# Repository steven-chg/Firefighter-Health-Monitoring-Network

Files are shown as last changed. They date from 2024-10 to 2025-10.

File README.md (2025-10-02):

# Firefighter Health Monitoring Network

A wearable health monitoring system that enables real-time tracking of firefighters' vital signs and environmental conditions during active duty. The system utilizes a mesh network of ESP32-based devices to continuously monitor and transmit critical health data including:

- Heart rate
- Motion 
- GPS location tracking
- Surrounding temperature measurements

## Key Features
- Wearable sensors integrated into firefighter gear
- Central monitoring hub for incident commanders with intuitive GUI 
- Real-time alerts for abnormal vital signs
- Mesh network with 300m+ urban range
- 2+ hour battery life in high temperature conditions

## Demo
Watch the demo video (https://youtu.be/pz7b-LwFBLg)

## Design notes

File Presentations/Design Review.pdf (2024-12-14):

ECE 445 Senior Design | Group 17: Firefighter Health Monitoring Network

# Group 17: Firefighter Health Monitoring Network

Members:
Bryan Chang (chchang9)
Kevin Huang (kuanwei2)
Steven YM Chang (sychang5)

# Contents

## I. Problem Statement and Solution II. Visual Aid III. High-Level Requirements IV. Block Diagram and Schematic V. Requirements and Verification Tables VI. Tolerance Analysis VII. Cost Analysis VIII. Schedule and Division of Labor IX. Ethics and Safety

# 1. Problem Statement and Solution

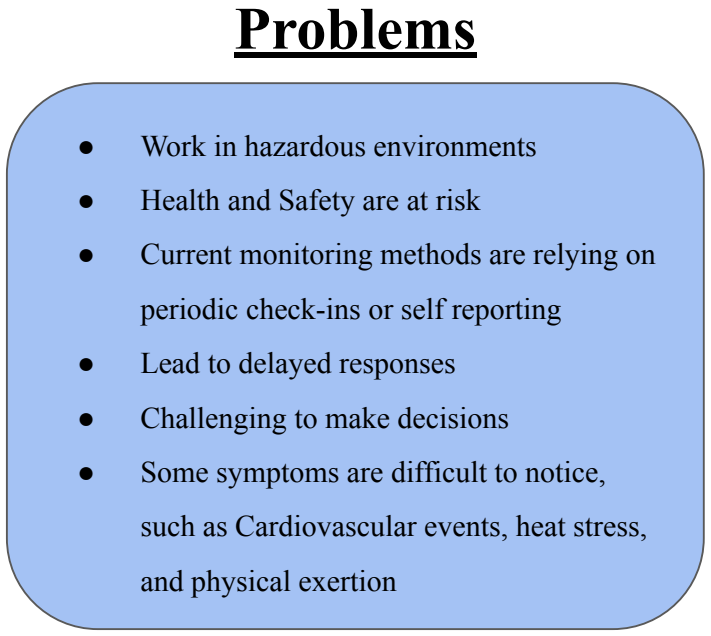
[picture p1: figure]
● Work in hazardous environments; ● Health and Safety are at risk; periodic check-ins or self reporting; ● Lead to delayed responses; ● Challenging to make decisions; and physical exertion; Problems

- Current monitoring methods are relying on
- Some symptoms are difficult to notice,

such as Cardiovascular events, heat stress,

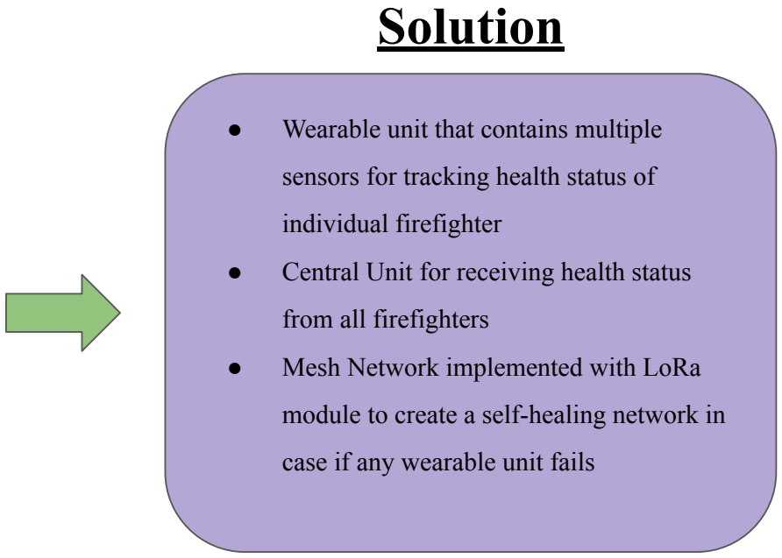
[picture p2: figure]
● Wearable unit that contains multiple; sensors for tracking health status of; individual firefighter; from all firefighters; ● Mesh Network implemented with LoRa; case if any wearable unit fails; Solution

- Central Unit for receiving health status

module to create a self-healing network in

# 2. Visual Aid

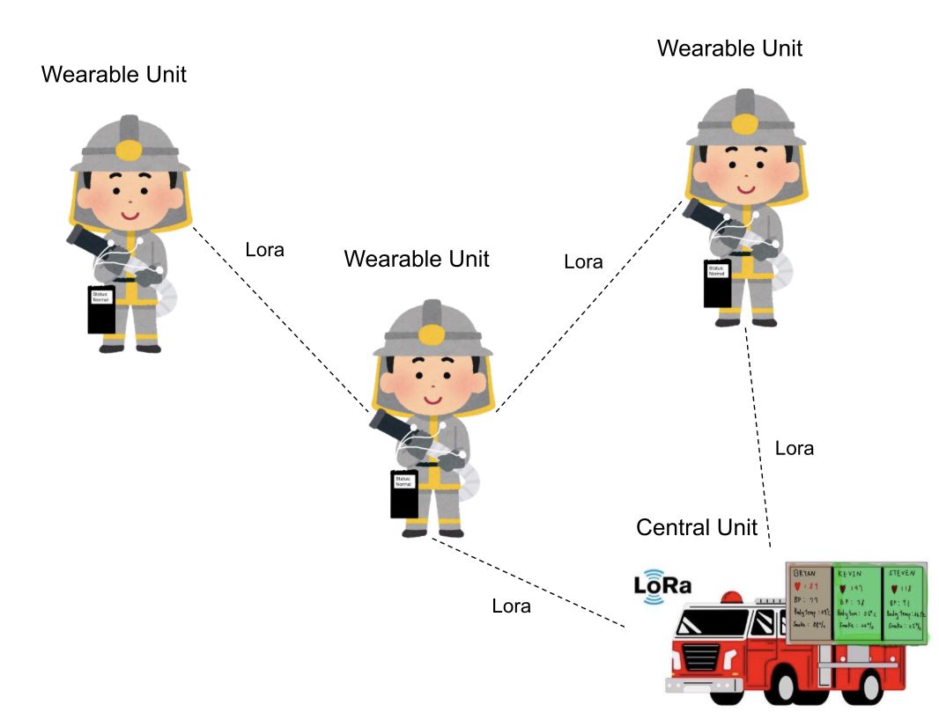
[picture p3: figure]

# 2. Visual Aid

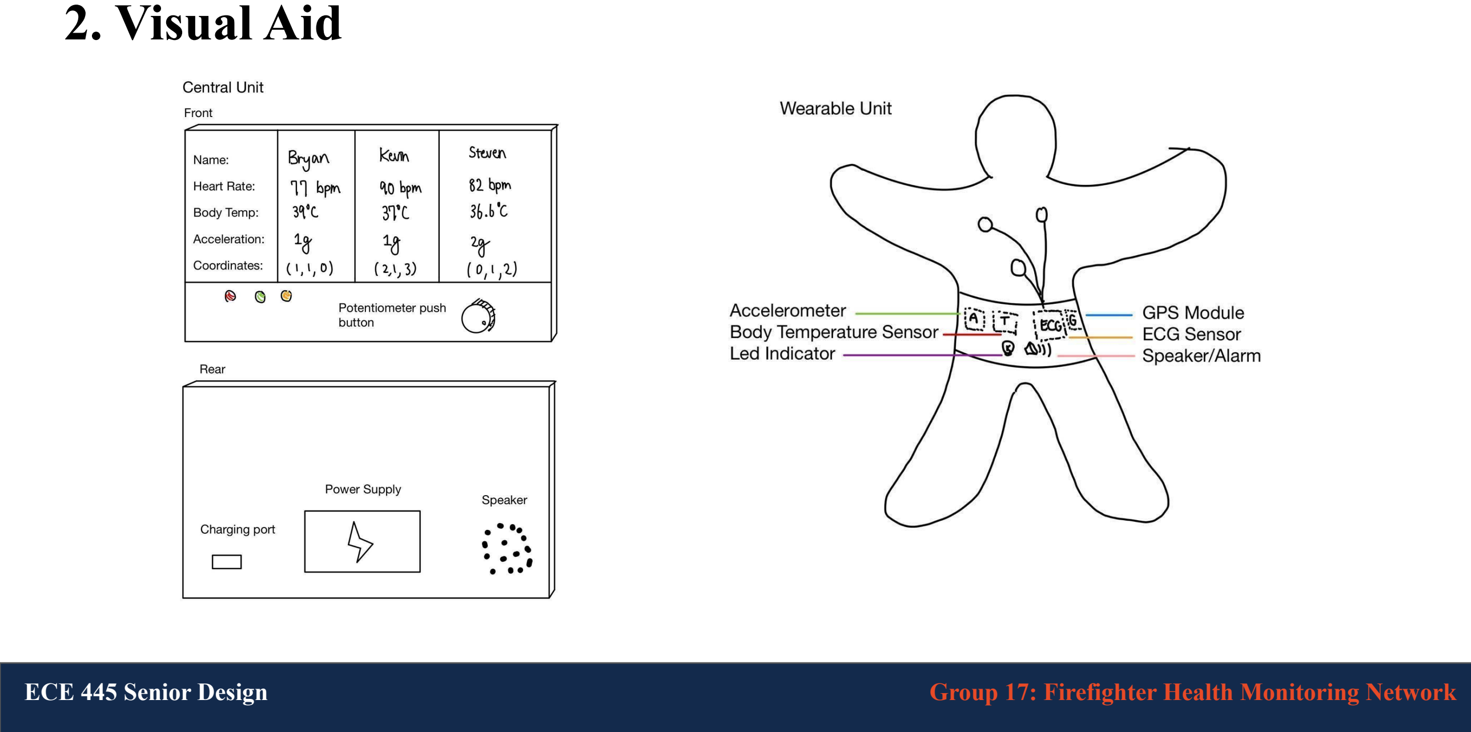
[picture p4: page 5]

# 3. High-Level Requirements

## 1. The system shall continuously monitor and transmit the following data with 90%

## accuracy and operate on a single charge for at least 2 hours in typical fire fighting

conditions above 30°C.

a. ECG/EKG Data
b. GPS Location
c. Motion Data
d. Surrounding Temperature Data

# 3. High-Level Requirements

## 2. The system shall generate buzzer alerts on the wearable unit and central monitor

## within 10 seconds of abnormal detections based on thresholds on data from sensors:

a. ECG/EKG Data
i. Heart rates <40 bpm or >150 bpm sustained for >30 seconds, or upon detection of specified

arrhythmias.

b. Motion Data
i. No significant motion detected for >60 seconds
c. Surrounding Temperature Data
i. Temperature exceeds 40°C for more than 3 minutes

# 3. High-Level Requirements

## 3. The mesh network shall maintain connectivity in challenging environments with a

## minimum range of 300 meters in urban settings and 1 km in open areas, using LoRa

## technology. The system shall automatically route data through multiple hops

## (firefighter-to-firefighter) to reach the central unit when direct communication is not

possible. End-to-end data transmission time from any firefighter to the central unit shall

not exceed 15 seconds, even when relaying through multiple nodes.

# 4. Block Diagram

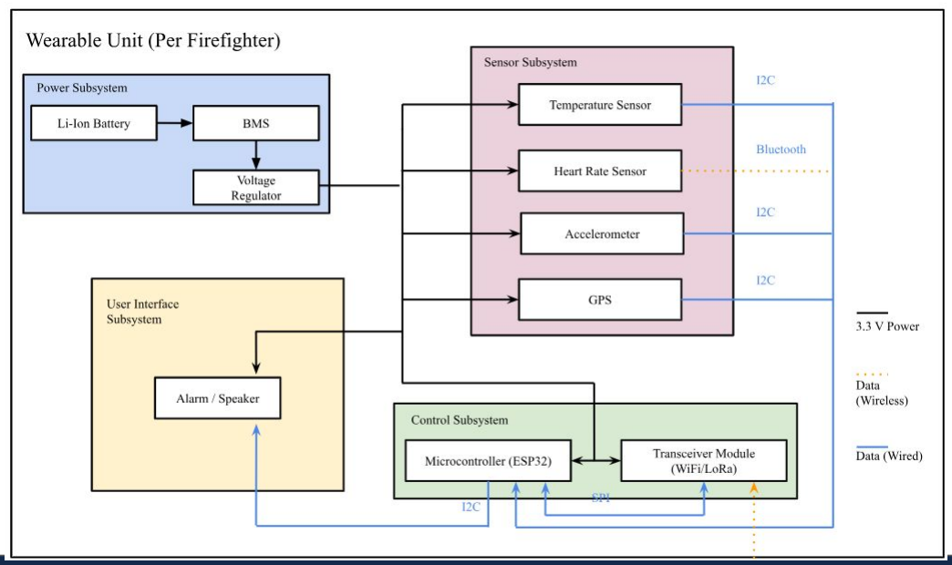
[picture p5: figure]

# 4. Block Diagram

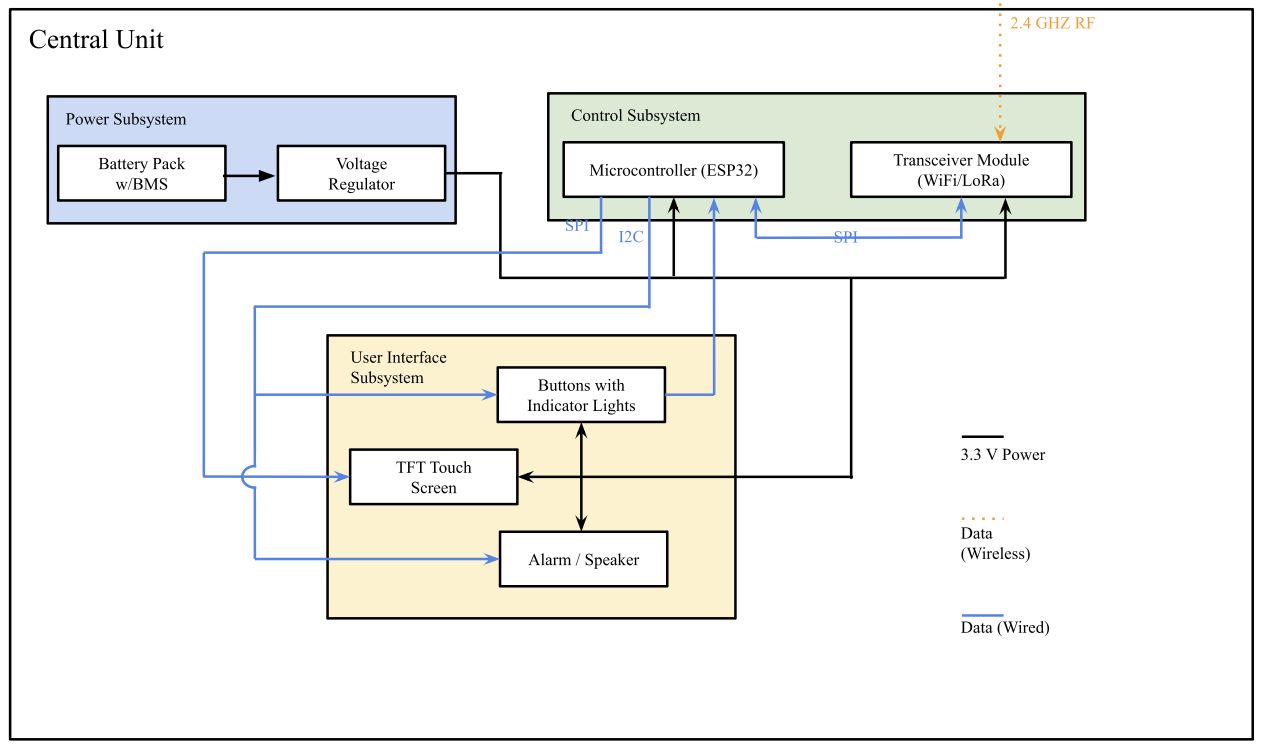
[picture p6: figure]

# 4. Wearable Unit Schematic

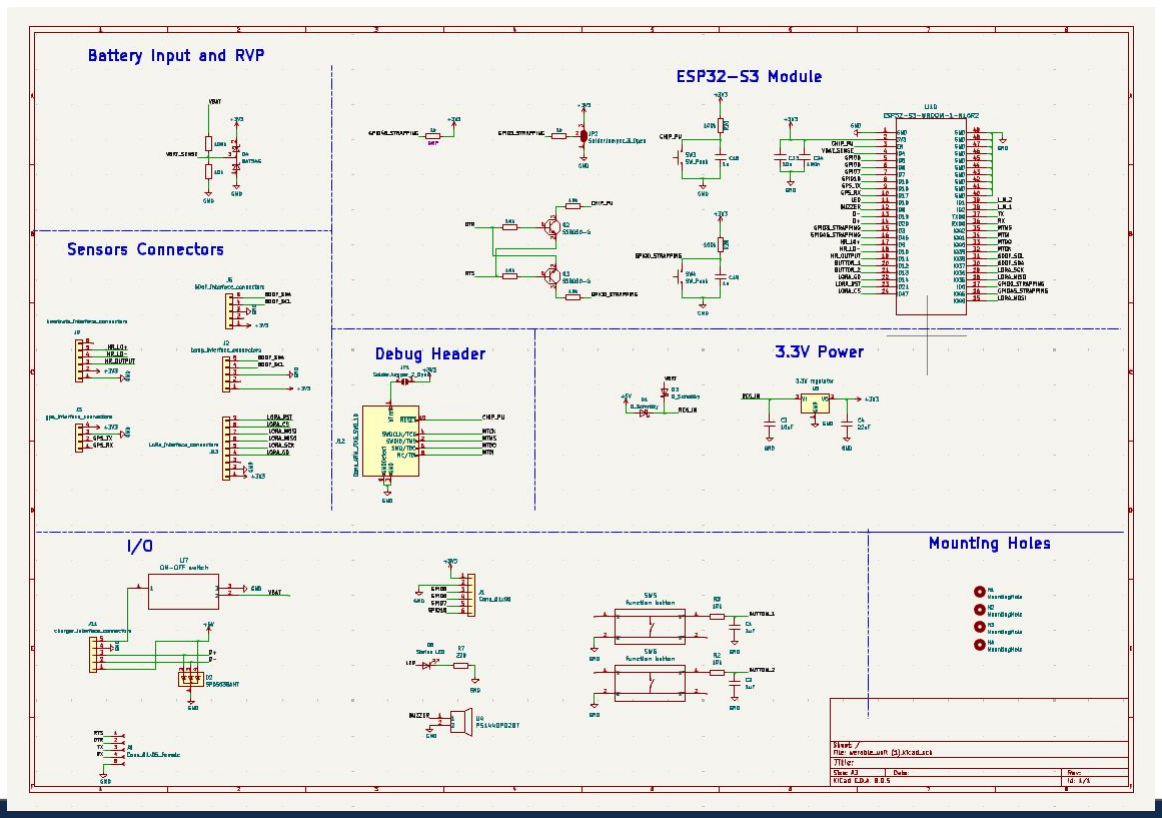
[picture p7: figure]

# 4. Wearable Unit

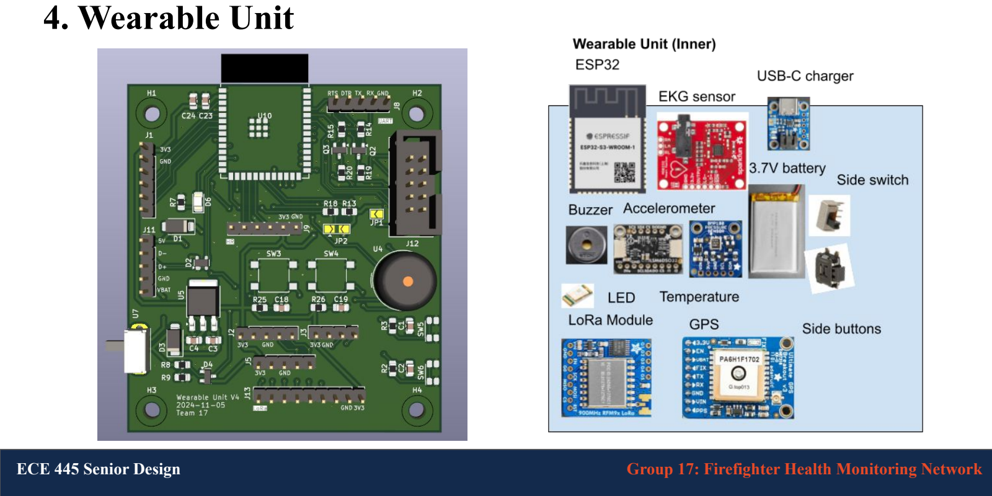
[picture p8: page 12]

# 5. Requirements and Verification

## Wearable Sensor Subsystem

This subsystem is responsible for continuously collecting real-time health and environmental data from individual firefighters. The sensors track vital signs like heart rate, surrounding temperature, and motion. The data is sent to the mesh network of the ESP32 and the central hub via reliable communication methods ESP-MESH and LoRa. The enclosure will be designed using 3D Computer-aided design software and printed out using a 3D printer with Polylactic acid material (PLA). Although PLA might have lower heat-resistance, other material like Polyetheretherketone (PEEK) could be replaced with the same design but with higher cost. For the purpose of this project, we will prioritize the design.

## 5. Requirements and Verification: Wearable Sensor Subsystem

Requirements | Verification

Wearable unit measures the surrounding temperature, heart rate, acceleration, and location of the user and sends it to the Central Monitoring Hub subsystem with a 90% accuracy.

1. Place a thermometer in a closed box and see if the values are the same for the device and the thermometer
2. Place the device on a person equipped with Apple Watch and validate the heartbeat count
3. Place the device on a steady surface and see if the acceleration read is equal to gravity (9.8m/s²
)
4. Measure the current coordinate with phone and validate the values from the gps sensor in the wearable unit
5. Output the readings to a terminal and confirm that the central unit is reading the values in real time

Alert is generated if a firefighter’s heart rate exceeds 150 bpm or falls below 40 bpm for more than 30 seconds. These thresholds account for both sustained tachycardia and bradycardia, indicating potential danger to the firefighter’s health.

1. Simulate the heart rate readings using ADALM2000
2. Set the wearable unit to monitor heart rates while gradually increasing to 160 bpm and decreasing to 35 bpm.
3. Validate that the wearable unit triggers an alert when heart rate exceeds 150 bpm for more than 30 seconds and when it falls below 40 bpm for the same duration.
4. Record response times and ensure alerts are activated correctly.

## 5. Requirements and Verification: Wearable Sensor Subsystem

Requirements | Verification

Alert is generated when the temperature exceeds 40°C for more than 3 minutes.

1. Place the device nearby a stove (or controlled heat source) to gradually increase the temperature around the wearable unit.
2. Monitor the wearable unit’s temperature sensor and record readings.
3. Validate that the wearable unit triggers an alert when the temperature exceeds 40°C for more than 3 continuous minutes.

Alert is generated if no significant movement is detected on the firefighter for over 60 seconds.

1. Secure the wearable unit to a stationary object or user.
2. Ensure that no movement is detected (within a calibrated margin) for a continuous period of 60 seconds, and verify that an alert is triggered at that moment.
3. Test with varying degrees of movement to ensure the threshold for "significant movement" is correctly calibrated.

## 5. Requirements and Verification: Wearable Sensor Subsystem

Requirements | Verification

In emergency situations where one or more alerts have been triggered, the GPS update frequency increases from every 30 seconds to every 5 seconds.

1. Trigger one of the alerts (heart rate, temperature, or motion) while monitoring the GPS update frequency.
2. Have the person wearing the monitoring unit be continuously moving.
3. Record the GPS update intervals to verify that the unit updates every 5 seconds during an alert condition.
Reset the device if the button is pressed | 1. | Press the button and verify the device restarts

# 5. Requirements and Verification

## Central Monitoring Hub Subsystem

The central hub acts as the control center for the network, gathering and visualizing health data from all firefighters in real time. It allows incident commanders to monitor the team’s health status, detect potential health risks, and respond quickly to emergencies. Its rugged design ensures that it remains operational during operations in harsh environments. The enclosure will be designed using 3D Computer-aided design software and printed out using a 3D printer with Polylactic acid material (PLA). Although PLA might have lower heat-resistance, other materials like Polyetheretherketone (PEEK) could be replaced with the same design but with higher cost. For the purpose of this project, we will prioritize the design.

## 5. Requirements and Verification: Central Monitoring Hub Subsystem

Requirements | Verification

The central unit display should be able to visualize the firefighter data holistically

Have three wearable device sending out simulated information to the central unit to verify it is able to display the firefighters data holistically

Send out a critical alert and change of LED color when abnormal activities occur

Manually input data with different conditions (normal, abnormal, dangerous) to the subsystem and observe whether the alert is turned on or off and whether the LED color changes according to the condition

# 5. Requirements and Verification

Power Subsystem

The power subsystem ensures that both the wearable units and the central hub have the energy to operate continuously.

Power Consumption for Wearable Unit:
ESP32 Microcontroller (DOIT ESP32 DEVKIT V1): 2.2V to 3.6V at ~100mA to 200mA (Active)
Electrocardiogram Sensor (ECG/EKG Sensor) (SEN-12650): 3.3V to 5V at ~10 mA
Temperature Sensor (BMP 180): 3.3V at ~5 µA (1 sample/second in standard mode)
Accelerometer for Motion Detection (LSM6DS032): 1.71V to 3.6V at ~1.5 mA (Active Operation) and ~0.5 µA (Low-Power Mode) GPS Module (MAX-M10S): 3.3V VCC at ~6mA to ~25mA
Buzzer (PS1240): 1.71V to 3.6V at ~20mA
LoRa Module for Extended Communication (RFM95W): 1.8V to 3.7V at 13.5 mA (Transmission) and 10 mA (Reception)

Power Consumption for Central Monitoring Unit:
ESP32 Microcontroller (DOIT ESP32 DEVKIT V1): 2.2V to 3.6V at ~100mA to 200mA (Active)
LoRa Module for Extended Communication (RFM95W): 1.8V to 3.7V at 13.5 mA (Transmission) and 10 mA (Reception) 3.5" TFT Touch Screen (HX8357D): 3.3V at ~20 mA to ~40 mA
Buzzer (PS1240): 1.71V to 3.6V at ~20mA

## 5. Requirements and Verification: Power Subsystem

Requirements | Verification

Wearable units should send alerts when the battery is low (below 10%) to the central unit.

Charge the device to 15% and operate the device until the battery drops down to 10% measuring with a multimeter to verify if the alert is sent.

Both the wearable unit and the central unit should last at least 2 hours on a single charge under typical operation conditions (temperatures above 30°C).

Simulate the sensor readings using ADALM2000, record the battery voltage every 5 mins to verify both the wearable unit and central unit has battery life longer than 2 hours.

# 5. Requirements and Verification

## User Interface Subsystem

The user interface is designed to provide incident commanders with a comprehensive and intuitive platform for monitoring firefighter health data in real time. It features a custom-designed graphical user interface on a 3.5" TFT touch screen, ensuring clear visibility and easy navigation.

## 5. Requirements and Verification: User Interface Subsystem

Requirements | Verification

Custom-designed graphical user interface (GUI) for the 3.5" TFT touch screen

1. Visually inspect GUI layout on the actual 3.5" screen
2. Perform touch interaction tests covering all UI elements
3. Verify responsiveness and accuracy of touch inputs

Real-time data visualization components (graphs, charts, status indicators)

1. Simulate data input for graphs, charts, and status indicators
2. Verify real-time updates of visualizations
3. Test different data scenarios (normal, critical, edge cases)
4. Measure and verify update frequency matches requirements

## 5. Requirements and Verification: User Interface Subsystem

Requirements | Verification

Alert management system with visual and auditory cues

1. Trigger various alert conditions
2. Verify visual cues appear correctly on screen
3. Test auditory alerts for proper sound and volume
4. Confirm alert prioritization works as designed
5. Test alert acknowledgment and dismissal functionality

User input handling for system configuration and data queries

1. Test all system configuration options
2. Verify data query functionality with various input parameters
3. Confirm changes are applied and persist after system restart
4. Test edge cases and invalid inputs for proper error handling

# 5. Requirements and Verification

## Mesh Network Integration

The LoRa Mesh Network provides long-range communication between nodes, ensuring connectivity even when traditional communication infrastructure is unavailable. This system enables reliable data transmission from firefighters' wearable units to the central hub in challenging environments.

## 5. Requirements and Verification: Mesh Network Integration

Requirements | Verification

End-to-end (including hops) data transmission time from any firefighter to the central unit shall not exceed 15 seconds, even when relaying through multiple nodes. Communication range of at least 1 km in open areas and 300 meters in urban environments.

Calculate the differences between the wearable unit packet sent time using gps time vs the central unit received time to verify the communication time is within 15 seconds.

The devices should be able to create its mesh network so even if a wearable is not directly in range to the central unit it can hop between the other wearable that’s in range to connect to the central unit

1. Set up a test environment with multiple wearable units and obstacles to force multi-hop routing.
2. Gradually move units out of direct range of the central hub.
3. Verify data from out-of-range units successfully reaches the central hub via other units.
4. Use network visualization tools to confirm the mesh topology.
5. Simulate node failures to test self-healing capabilities.
6. Measure and compare latency for direct vs multi-hop communications.

## 5. Requirements and Verification: Health Status Assessment Data Processing

Requirements | Verification

For ECG signals, use filtering techniques, such as a low-pass filter with a cut-off frequency of 100 Hz to remove high-frequency noise, combined with a stop-band filter around 60 Hz to eliminate electrical noise interference

1. Use Matlab to plot raw and filtered ECG signals in the time domain.
2. Compare frequency spectra of raw and filtered signals using FFT.
3. Verify attenuation above 100 Hz and at 60 Hz.

For ECG signals, apply the Butterworth or Chebyshev filter to ensure sufficient attenuation of at least -60 dB/decade in the stopband, preserving the integrity of the ECG signal’s primary components (P, QRS, T waves).

1. Apply the chosen filter (Butterworth or Chebyshev) to a known ECG signal.
2. Plot the frequency response of the filter and measure the attenuation in the stopband to confirm it meets or exceeds -60 dB/decade.
3. Compare the filtered signal with the original in both time and frequency domains to ensure preservation of P, QRS, and T waves.
4. Perform a quantitative analysis (e.g., cross-correlation) between original and filtered signals to verify integrity of primary components.

# 6. Tolerance Analysis

## LoRa Communication Range

Requirement:

The LoRa module must ensure a communication range of at least 1 km in open areas and 300 meters in urban or obstructed environments.

Analysis:

To assess the feasibility of meeting this requirement, we'll consider the following factors:

1. LoRa Link Budget
2. Environmental Factors
3. Transmission Power

# 6. Tolerance Analysis

## 1. LoRa Link Budget

Link Budget = Transmitter Power + Transmitter Antenna Gain - Path Loss + Receiver Antenna Gain - Receiver Sensitivity

Assuming typical values for a LoRa system:

- Transmitter Power: 14 dBm (25 mW)
- Transmitter Antenna Gain: 2 dBi
- Receiver Antenna Gain: 2 dBi
- Receiver Sensitivity: -137 dBm (for SF12, BW125)

# 6. Tolerance Analysis

The path loss for 1 km in an open area can be estimated using the free-space path loss formula:

FSPL (dB) = 20 * log10(d) + 20 * log10(f) - 147.55

Where:

- d = distance in meters (1000)
- f = frequency in Hz (assume 915 MHz for US LoRa)

FSPL = 20 * log10(1000) + 20 * log10(915*10^6) - 147.55 ≈ 92 dB

Link Budget = 14 + 2 - 92 + 2 + 137 = 63 dB

This positive link budget suggests that communication at 1 km in open areas is feasible.

## 1. LoRa Link Budget

# 6. Tolerance Analysis

In urban or obstructed environments, additional path loss occurs due to obstacles. We can estimate this additional loss to be around 20-30 dB.

For 300 meters in an urban environment:

- FSPL = 20 * log10(300) + 20 * log10(915*10^6) - 147.55 ≈ 81 dB
- Total Path Loss = 81 dB + 25 dB (urban environment) = 106 dB
- Link Budget = 14 + 2 - 106 + 2 + 137 = 49 dB

This positive link budget indicates that communication at 300 meters in urban environments is also feasible.

## 2. Environmental Factors

# 6. Tolerance Analysis

The analysis uses 14 dBm (25 mW) as the transmission power. Many LoRa modules can transmit at up to 20 dBm (100 mW), which would

add an extra 6 dB to the link budget if needed.

## 3. Transmission Power

# 6. Tolerance Analysis

## Resilience of Mesh Network Communication to Maximum Allowable Delay

Requirement:

- Node Connectivity: Each wearable device must communicate with neighboring devices to relay data back to the central hub.
- Maximum Latency: The total transmission delay from a firefighter's device to the central unit must not exceed 15 seconds.

Analysis:

We'll consider the following factors:

1. Transmission Time Using LoRa
2. Maximum Number of Hops

# 6. Tolerance Analysis

LoRa communication allows for long-range transmission with low data rates. LoRa uses a feature called the spreading factor (SF) to control

the trade-off between data rate and range. As the distance between the transmitter and receiver increases, you may need to increase the

spreading factor to maintain reliable communication.

Assuming a payload size of 400 bytes (3200 bits) and using a data rate of 3.13 kbps ( for 3km in Open Areas and 500m in Urban

Environments):

Transmission Time = 3200 bits / 3130 bps = 1.02 seconds (1022 ms)

This calculation indicates that transmitting data between neighboring firefighters will take approximately 1022 ms per hop.

## 1. Transmission Time Using LoRa

# 6. Tolerance Analysis

Given a maximum allowable total delay of 15 seconds, we can calculate the maximum number of hops n:

n=15000 ms / 1022 ms ≈ 14.68 hops

While this theoretical maximum is high, practical application in a firefighting context is much lower. Considering a typical firefighting team

size of 4 to 10 members, our analysis demonstrates that the mesh network can reliably support up to 14 hops between firefighters while still

adhering to the 15-second maximum allowable delay for data transmission. This is based on a payload size of 400 bytes and a data rate of

3.13 kbps using LoRa communication.

## 2. Maximum Number of Hops

# 6. Tolerance Analysis

## Power Management

Requirement:

- The battery should last at least 2 hours on a single charge under typical operation conditions (temperatures above 30°C). Analysis:
1. Battery Capacity (C): 2000 mAh lithium-ion battery.
2. Power Consumption (P): Total power consumption depends on the combined power draw of the sensors, ESP32 microcontroller, and communication modules (LoRa, ESP-MESH). The following current draw is based on the upper bound of current consumption data included in the power subsystem section.
3. Battery Discharge Efficiency (n): Efficiency factor, assume 60% due to heat and inefficiencies in power delivery (conversion losses).

# 6. Tolerance Analysis

- Power Consumption of each Components
- ESP32 microcontroller: 200 mA during active use.
- EKG sensor: 10 mA.
- Temperature sensor: 5 µA.
- GPS sensor: 25 mA
- Motion sensors (accelerometer/gyroscope): 1.5 mA.
- LoRa module: 13.5 mA during transmission.
- Buzzer: 20 mA
- P = 200 mA + 10 mA+ 5 µA +25 mA+ 1.5 mA + 13.5 mA + 20 mA<=271mA

## 1. Total Power Consumption

# 6. Tolerance Analysis

To calculate the battery runtime, we can use the following formula: t = C*nP

Where:
- t is the battery runtime in hour
- C is the battery capacity in mAh
- n is the battery discharge efficiency
- P is the total power consumption

P = 200 mA + 10 mA+ 5 µA +25 mA+ 1.5 mA + 13.5 mA + 20 mA<=271mA

As a result, we get t = C*n / P=2000*0.6 / 271 = 4.43hr >= 4hr

Thus, the battery is expected to last approximately 4 hours under typical usage conditions, which satisfies the requirement of 2 hours of operation.

## 2. Battery Runtime Calculation

# 7. Cost Analysis

## Three Subcategories

## 1. Purchased Components and Parts

## 2. Labor and Wages

## 3. Other Resources

## 1. Purchased Components and Parts

Description | Manufacturer | Part Number | Quantity | Unit Price | Extended Price | Part Link
GPS | SparkFun | MAX-M10S | 1 | $44.95 | $44.95 | Link (https://www.sparkfun.com/products/18037)
LoRa Transceiver | Adafruit | RFM95W | 3 | $19.95 | $59.85 | Link (https://www.adafruit.com/product/3072?gad_source=1)

3.5" TFT LCD

Single Lead Heart

Display | Adafruit | HX8357D | 1 | $39.95 | $39.95 | Link (https://www.adafruit.com/product/2050)
Rate Sensor | Sparkfun | SEN-12650 | 1 | $21.50 | $21.50 | Link (https://www.digikey.com/en/products/detail/sparkfun-electronics/SEN-12650/5824153?gad_source=1)
Temperature Sensor | Adafruit | BMP 180 | 1 | $9.95 | $9.95 | Link (https://www.adafruit.com/product/1603)

Accelerometer and
Gyroscope | Adafruit | LSM6DS032 | 1 | $12.50 | $12.50 | Link (https://www.adafruit.com/product/4692?gad_source=1)
Piezo Buzzer | PDK Corporation | PS1240 | 2 | $1.50 | $3.00 | Link (https://www.adafruit.com/product/160)
Lithium Ion Battery | Adafruit | 3.7V 2000mAh | 3 | $12.50 | $37.50 | Link (https://www.adafruit.com/product/2011)
Micro-Lipo Charger | Adafruit | Micro-Lipo Charger | 3 | $4.90 | $14.70 | Link (https://www.adafruit.com/product/4410)
ESP32-WROOM | Espressif Systems | DOIT ESP32 DEVKIT V1 | 3 | $15.98 | $47.94 | Link (https://www.amazon.com/ESP32-WROOM-32-Development-ESP-32S-Bluetooth-Arduino/dp/B084KWNMM4)

Total Purchased Components Price: $291.84

## 2. Labor and Wages

- Annual salary for Computer Engineering students as a reference ($109,176/yr according to the Grainger College of Engineering)
- The number of work days in a year is approximately 365*(5/7) ≈ 261 days.
- Assume a person works 8 hours a day and 261 days per year
- Wage per hour is roughly $109,176 / (261*8hr) ≈ $52/hr.
- Over the course of 2 months, we plan to spend an average of 2 hours per day. Thus, the total labor cost will be $52/hr * 2 hr/day * 60

days * 3 students = $18720.

## 3. Other Resources

- Design doesn’t require any customized enclosure for the product, we do not plan to order any part from the ECE Machine shop.
- Plan to use the Senior Design Lab resources, such as PCB creation, multimeters for debugging, and soldering, which has no cost.

# 7. Cost Analysis

## Total Cost

## 1. Purchased Components and Parts: $291.84

## 2. Labor and Wages: $18,720

## 3. Other Resources: $0

## Total Cost: $19,011.84

# 8. Schedule and Division of Labor

Role | Name | Specialized Work
Network Communications Specialist | Kevin Huang | ● Mainly focus on Mesh Network and Data Transfer ● In charge of implementing and optimizing the mesh network ● Will ensure reliable data transmission in challenging environments
Lead Hardware Engineer | Bryan Chang | ● Mainly focus on PCB Design and Battery ● Responsible for overseeing the design and integration of the wearable device hardware ● Will focus on power management to ensure the 2-hour battery life goal is met
Software Integration Lead | Steven YM Chang | ● Mainly focus on User Interface and Monitoring Hub Software ● Responsible for developing the central monitoring hub software ● Will work on data processing and alert generation algorithms

# 8. Schedule and Division of Labor

Week | Task | Person
09/30 ~ 10/06 | Finalize Proposal (due on 10/04 at 11:59 PM) | Everyone
| Complete Design Document (due on 10/03 at 11:59 PM) | Everyone
| Design Review with Professor and TAs (10/08 at 1:00 PM) | Everyone
| Order Components | Everyone
| Learn to use LoRa Module and ESP-32 | Kevin
10/7 ~ 10/13
Learn to use GPS, EKG, and temperature sensors | Steven
Finish PCB Design and Review (due on 10/13 at 3-5 PM) | Bryan
| First Round PCBway Order (due on 10/15 at 4:45 PM) | Everyone
| Team Evaluation I (due on 10/16 at 11:59 PM) | Everyone
| Get LoRa Transceivers to communicate | Kevin
| Start Designing the User interface and LCD | Steven & Bryan
| Learn how to do power management of Lithium-ion battery | Bryan

10/14 ~ 10/20

10/21 ~ 10/27 | Second Round PCBway Order (due on 10/22 at 4:45 PM) | Bryan
| Assemble the Central Unit | Bryan
| Collect data from each sensor and design the algorithm for automatic alert | Steven & Kevin
| Implement the mesh network | Kevin & Bryan
| Third Round PCBway Order (due on 10/29 at 4:45 PM) | Bryan

10/28 ~ 11/03

Assemble the Wearable Unit | Bryan & Steven
Test the mesh network to guarantee reliable data transmission | Kevin
Implement algorithm for abnormal EKG/ECG activities | Steven & Kevin
11/04 ~ 11/10 | Fourth Round PCBway Order (due on 11/05 at 4:45 PM) | Bryan
| Individual Progress Report (due on 11/06 at 11:59 PM) | Everyone
| Finalized Design Document (due on 11/10 at 11:59 PM) | Everyone

# 8. Schedule and Division of Labor

11/11 ~
11/17

Fifth Round PCBway Order (due on 11/12 at
4:45 PM)

Bryan

Start Integrating the Software | Steven
Mount LCD & User Interface | Bryan & Kevin
Finish Verifications of Sensor Results | Steven & Kevin
Finalize Data Transmission and Alert Triggers | Bryan
Practice Demo | Everyone
11/18 ~ 11/24 | Mock Demo (during weekly TA meeting) | Everyone
| Team Contract Fulfillment (due on 11/24 at 11:59 PM) | Everyone
| Fix any Errors (if necessary) | Everyone

11/25 ~
12/01
Fall Break | Everyone
Work on Final Presentation and Paper | Everyone
Practice Final Demo | Everyone
12/02 ~ 12/08 | Final Demo with Instructor and TAs | Everyone
| Continue working on Final Paper | Everyone
| Mock Presentation with Comm and ECE TAs | Everyone
12/09 ~ 12/15 | Final Presentation with Instructor and TAs | Everyone
| Final Paper (due on 12/11 at 11:59 PM) | Everyone
| Lab Notebook (due on 12/12 at 11:59 PM) | Everyone

# 9. Ethics and Safety

Data Privacy and Security

According to the ACM Code of Ethics, members should "respect the privacy of others" and "honor confidentiality” [8]. Monitoring firefighters'

health data involves collecting sensitive personal information such as heart rate, surrounding temperature, and potentially location data. Any breach

of this data could lead to privacy violations.

Solution: Implement strict access controls so only authorized personnel (e.g., the incident commander) can view the data.

Informed Consent

Firefighters must be fully informed about what data is being collected, how it will be used, and their rights to privacy under the IEEE Code of

Ethics (Clause 1). This includes consent not only for data collection during their active duty but also how their data may be used in post-incident

reviews.

Solution: Ensure that firefighters provide informed consent before wearing the monitoring devices. Offer clear and accessible explanations of what

data will be collected, why, and how it will be protected.

# 9. Ethics and Safety

Fire and Water Resistance

Given that firefighters operate in extreme environments, we made the design choice to house the wearable unit within the protective layers of the

firefighter’s suit. This placement ensures that the components are shielded from direct exposure to high temperatures and water. While this reduces

risks, we acknowledge that no system can fully eliminate all dangers. We aim to improve safety standards by enhancing the protection of critical

electronics without compromising the function or comfort of firefighting gear. By situating the electronics inside the suit, we significantly reduce

the risk of component failure due to environmental factors, contributing to both firefighter safety and operational reliability, in line with the IEEE’s

Code of Ethics Section I.5 to "be honest and realistic in stating claims or estimates" [3].

# 9. Ethics and Safety

Lithium-Ion Battery Safety

Lithium-ion batteries, while efficient, can pose risks such as overheating or physical damage, leading to dangerous conditions like thermal

runaway—a situation where excessive heat can trigger a self-sustaining reaction resulting in fire or explosion [5]. To mitigate these risks, we will

implement general safety precautions when using lithium-ion batteries, including:

- Proper Storage: Store batteries in a cool, dry place away from flammable materials to prevent overheating and reduce fire risk.
- Avoiding Physical Damage: Ensure that batteries are not exposed to impacts, punctures, or other physical stresses that could compromise

their integrity.

- Safe Charging Practices: Use compatible chargers and avoid overcharging batteries, as this can lead to thermal runaway. Disconnect

chargers once the battery reaches full charge. Ensure that charging is performed using LiPo safety bags.

- Regular Inspections: Conduct regular inspections of the battery for signs of swelling, leakage, or corrosion, and replace any batteries

displaying these signs

By integrating these precautions and following best practices for lithium-ion battery usage, our design aligns with the IEEE’s ethical commitment

to enhancing the safety, health, and welfare of the public [3]. These measures ensure the reliability and long-term safety of our monitoring system,

supporting firefighter operations in hazardous environments.

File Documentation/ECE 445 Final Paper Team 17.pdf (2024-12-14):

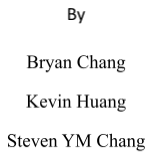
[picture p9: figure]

### Abstract

The Firefighter Health Monitoring Network addresses the challenges of real-time health monitoring for firefighters operating in hazardous environments. The system integrates wearable sensor units into firefighter gear to continuously monitor vital signs, including heart rate, motion, ambient temperature, and location tracking. Processed data and alerts are transmitted via a resilient mesh network to a central monitoring hub, providing incident commanders with immediate awareness of the health status of all firefighters on scene. The wearable units achieve 90% accuracy in data collection and can operate for at least 2 hours on a single charge in typical fire fighting conditions above 30°C when housed within firefighter suits. Alerts are generated within 10 seconds of detecting abnormal vital signs or lack of motion. The mesh network maintains connectivity with a minimum range of 250 meters in urban settings and 600 meters in open areas, with a maximum end-to-end transmission time of 15 seconds.

### Contents

### 1. Introduction

### 1.1 Problem

Firefighters operate in extremely hazardous environments where their health and safety are constantly at risk. Current methods of monitoring firefighter health during active duty are limited, often relying on periodic check-ins or self-reporting. This can lead to delayed responses to health emergencies, such as heat exhaustion, overexertion, or cardiac events. Incident commanders lack real-time, comprehensive health data on their team, making it challenging to make informed decisions about resource allocation and firefighter safety.

Research supports the critical nature of this problem:
- Cardiovascular events: Studies have shown that firefighters are at a significantly higher risk of on-duty cardiovascular events compared to other professions. Kales et al. (2007) found that 45% of on-duty firefighter fatalities were due to sudden cardiac death, highlighting the need for continuous cardiac monitoring [4].
- Heat stress: A study by Horn et al. (2013) demonstrated that core body temperature can rise to dangerous levels during firefighting activities, with some firefighters reaching temperatures above 38.5°C (101.3°F), which is associated with heat exhaustion and cognitive impairment [2].
- Physical exertion: Rodríguez-Marroyo et al. (2012) reported that firefighters routinely work at 60-95% of their maximum heart rate during emergency operations, indicating high levels of physiological stress that require monitoring [6].
- Limitations of current monitoring: Coca et al. (2011) highlighted the inadequacy of periodic vital sign checks, noting that they fail to capture the dynamic nature of physiological responses during firefighting activities [1].
- Decision-making challenges: Smith et al. (2016) emphasized the importance of real-time physiological data for incident commanders to make informed decisions about crew rotation and resource allocation, which current systems do not adequately provide [7].

These research findings underscore the urgent need for a comprehensive, real-time health monitoring system for firefighters that can track vital signs such as heart rate and movement patterns through accelerometry. Such a system would enable early detection of potential health emergencies and support more informed decision-making by incident commanders, ultimately enhancing firefighter safety and operational effectiveness.

### 1.2 Solution

We propose the development of a "Firefighter Health Monitoring Network" - a system of wearable devices integrated into firefighters' gear that continuously monitors vital signs and environmental conditions. The system uses a mesh network of ESP32-based devices to transmit real-time health data to a central monitoring hub. This allows incident commanders to have immediate, comprehensive awareness of their team's health status, enabling quick decision-making and potentially life-saving interventions.

### 1.3 High-Level Requirements

1. The system shall continuously monitor and transmit the following data with 90% accuracy and operate on a single charge for at least 2 hours in typical fire fighting conditions above 30°C.
a. Heart Rate Data
b. GPS Location
c. Motion Data
d. Surrounding Temperature Data
2. The system shall generate buzzer alerts on the wearable unit and central monitor within 10 seconds of abnormal detections based on thresholds on data from sensors:
a. Heart Rate Data
i. Heart rates <40 bpm or >150 bpm sustained for >30 seconds.
b. Motion Data
i. No significant motion detected for >60 seconds
c. Surrounding Temperature Data
i. Temperature exceeds 40°C for more than 3 minutes
3. The mesh network shall maintain connectivity in challenging environments with a minimum range of 250 meters in urban settings and 600 meters in open areas, using LoRa technology. The system shall automatically route data through multiple hops (firefighter-to-firefighter) to reach the central unit when direct communication is not possible. End-to-end data transmission time from any firefighter to the central unit shall not exceed 15 seconds, even when relaying through multiple nodes.

### 1.4 Subsystem Overview

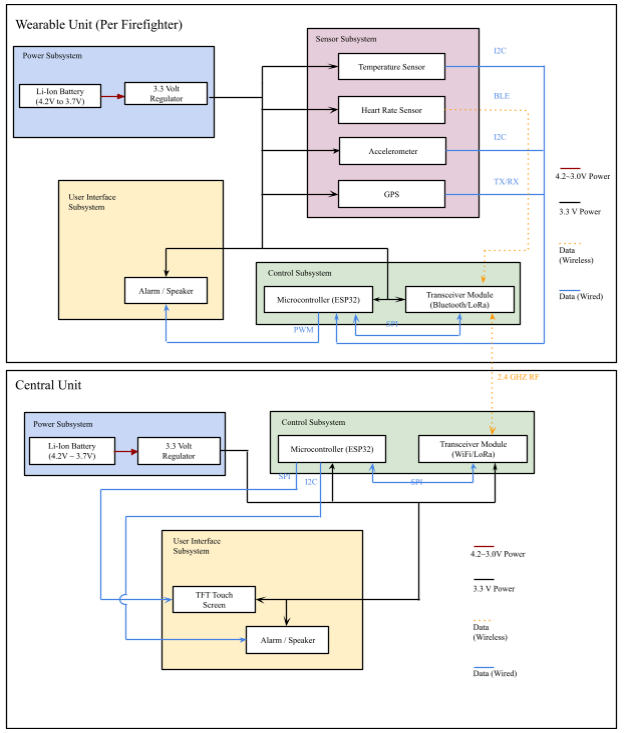
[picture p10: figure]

Figure 1. Block Diagram

These subsystems work in concert to provide a comprehensive, real-time health monitoring solution for firefighters. The wearable sensor units play a more significant role in data processing and alert generation. They continuously collect and analyze the sensor data, checking for anomalies and generating alerts when necessary. The processed data and alert status are then transmitted via the mesh network to the central monitoring hub, which serves as a centralized platform for displaying the information and enabling incident commanders to make informed decisions. The power management subsystem and mesh network subsystem support the continuous and reliable operation of the wearable units and the communication between them and the central hub.

### 2 Design

### 2.1 Equations and Simulations

The reliability of our Firefighter Health Monitoring Network depends critically on the performance of its LoRa communication system. To validate our design, we analyzed the LoRa link budget using the
equation:
Link Budget = Transmitter Power + Transmitter Antenna Gain + Transmitter Antenna Gain
− Patℎ Loss + Receiver Antenna Gain − Receiver Sensitivity | (1)
Using typical LoRa system values (Transmitter Power: 14 dBm, Antenna Gains: 2 dBi each, Receiver Sensitivity: -137 dBm), we calculated the feasibility of our range requirements. For open areas with a 1
km range requirement, we calculated the Free Space Path Loss (FSPL) using the equation:
FSPL (dB) = 20 * log10(d) + 20 * log10(f) − 147. 55 | (2)
where d is the distance in meters (1000) and f is the frequency (915 MHz for US LoRa). This calculation yielded an FSPL of 92 dB, resulting in a positive link budget of 63 dB, confirming the feasibility of our open-area range requirement.
For urban environments with a 300-meter requirement, we considered additional path loss factors. The basic path loss at this distance is 81 dB, and we accounted for an additional 25 dB loss due to urban obstacles. This resulted in a total path loss of 106 dB and a positive link budget of 49 dB, validating our urban range requirement.
We also analyzed the mesh network's latency requirements. With a payload size of 400 bytes (3200 bits) and a data rate of 5 kbps, we calculated a transmission time of 0.64 seconds per hop. Given our
maximum allowable end-to-end delay of 15 seconds, the system can theoretically support up to 23 hops while maintaining required performance, which is more than adequate for typical firefighting team sizes. For battery lifetime calculation, we analyzed the power consumption of all components using a
2000mAh lithium-ion battery. The calculation uses the following equation:
Battery Runtime (ℎours) = (Battery Capacity * Efficiency) / Total Current Draw | (3)
Where: Battery Capacity = 2000mAh Efficiency = 60% (accounting for temperature and conversion losses) Total Current Draw = sum of all component currents:
- ESP32 microcontroller: 200mA
- ECG/EKG sensor: 10mA
- Temperature sensor: 0.005mA

- GPS sensor: 25mA
- Accelerometer: 1.5mA
- LoRa module: 13.5mA
- Buzzer: 20mA
Total Current Draw = 200 + 10 + 0. 005 + 25 + 1. 5 + 13. 5 + 20 = 271mA | (4)
Battery Runtime = (2000mAℎ * 0. 60) / 271mA = 4. 43 ℎours | (5)
This calculation shows that our system can operate for approximately 4.4 hours on a single charge, which exceeds our requirement of 2 hours operation time. The efficiency factor of 60% accounts for real-world conditions including temperature effects on the battery and power conversion losses.

### 2.2 Design Alternatives, Description and Justification

The Firefighter Health Monitoring Network consists of several interconnected subsystems that work together to collect, transmit, process, and display critical health and environmental data. Each subsystem has been carefully designed and optimized through testing and iteration to ensure reliability in firefighting conditions.

### 2.2.1 Wearable Unit Subsystem

The wearable sensor subsystem integrates seamlessly into firefighters' gear, featuring carefully selected components for reliability in harsh conditions. Initially, we planned to use an ECG/EKG sensor for heart rate monitoring. However, testing revealed high sensitivity to muscle contractions, which would generate unreliable readings during intense physical activity. We switched to a commercial Bluetooth heart rate strap sensor (the specific model we used is Garmin HRM Dual), which maintains ±5 bpm accuracy even during active movement.
The unit also includes a temperature sensor operating from 0°C to 65°C with ±1.0°C accuracy, an accelerometer with ±2g resolution for motion detection, and a GPS module providing ±20m position accuracy. An ESP32 microcontroller with dual-core 240 MHz processor, 520 KB SRAM, and 4 MB flash memory processes the sensor data locally, enabling quick alert generation when measurements exceed predetermined thresholds.

### 2.2.2 Central Monitoring Hub Subsystem

The central hub serves as the command center, built around a robust ESP32-based processing unit that handles data aggregation and analysis. A 3.5" TFT touch screen provides real-time data visualization and alert management through a custom-designed interface. The hub processes incoming data streams from multiple wearable units simultaneously, displaying each firefighter's status and location on an intuitive dashboard.
The interface allows incident commanders to quickly assess the situation through color-coded status indicators and detailed data views. Alert conditions are prominently displayed with both visual and auditory notifications, ensuring immediate attention to potential health risks or emergency situations.

### 2.2.3 Power Management Subsystem

The power subsystem uses 2000mAh lithium-ion batteries, chosen for their high energy density and reliable performance. Our power management circuit optimizes battery life through efficient voltage regulation and smart power distribution. The system operates for 4.4 hours on a single charge (calculated with 60% efficiency factor), exceeding our 2-hour requirement.
Key power-saving features include:
- Dynamic sensor sampling rates based on activity levels
- Low-power modes during periods of inactivity
- Intelligent battery monitoring with low-battery alerts at 10% capacity

### 2.2.4 Mesh Network Subsystem

The mesh network employs LoRa (Long Range) technology for its superior range and building penetration capabilities. Operating at 915 MHz (North American band), the system maintains connectivity across 600 meters in open areas and 250 meters in urban environments, verified through link budget analysis showing positive margins of 63 dB and 49 dB respectively.

Node Architecture
Each wearable unit functions as both a data source and a relay node within the network, while the central unit functions as the terminal node. The system implements a hierarchical node structure:
1. Node ID 1: Reserved for the central monitoring hub, serving as the terminal node
2. Node IDs 2+: Assigned to individual wearable units
This architecture enables multi-hop message propagation while providing clear message termination criteria when data reaches the central hub.

Message Handling and Routing
Messages in the network contain several key components:
1. Sender ID (1 byte)
2. Hop Count (1 byte)
3. Message ID (4 bytes)
4. Alert Status Flags (4 bytes)
5. Sensor Data Payload (variable length)
To prevent message loops and duplicates, the system implements a robust message tracking mechanism:

#define MAX_TRACKED_MESSAGES 50

unsigned long trackedMsgIDs[MAX_TRACKED_MESSAGES];
int trackedIndex = 0;

Each node maintains a circular buffer of recently processed message IDs. When a message is received, the node:
1. Checks if the message ID exists in its tracking buffer
2. If new, processes the message and adds its ID to the buffer
3. If duplicate, discards the message to prevent network congestion The message forwarding logic implements selective retransmission:

void sendForwardMessage(int originalSender, int numHop, unsigned long msgID, ...) { LoRa.beginPacket();
LoRa.write(originalSender); // Preserve original sender ID
LoRa.write(numHop + 1); // Increment hop count
// ... write message data ...
LoRa.endPacket();
}

Hop Management
Messages can traverse up to 23 hops while maintaining end-to-end latency under 15 seconds. This is achieved through:
1. Hop count tracking in each message
2. Minimal processing overhead per hop (~640ms per transmission)
3. Efficient message structure minimizing packet size
The hop limit calculation is based on:
1. Maximum allowed delay = 15000ms
2. Per-hop transmission time ≈ 640ms
3. Maximum hops = 15000/640 ≈ 23 hops

Signal Strength Considerations
To maintain reliable communication, each node monitors the Received Signal Strength Indicator (RSSI) of incoming messages:

Serial.print("RSSI ");
Serial.println(LoRa.packetRssi());

This information helps validate link quality and can be used to optimize routing paths in future iterations of the system.

### 2.2.5 Software and Data Processing Subsystem

The software architecture of the wearable unit emphasizes robust health monitoring and reliable alert generation through carefully structured data management and time-based verification systems. This section details the key components and design decisions that enable accurate health status monitoring and emergency detection. The software components are designed with modularity in mind, allowing for easy updates and the addition of new features as requirements evolve.

Alert Status Management
The system utilizes a comprehensive data structure to track various alert conditions and their temporal characteristics. This structure, implemented as the AlertStatus struct, maintains the current state of all monitored parameters and their associated timestamps:

struct AlertStatus {

bool isHRAlert; | // Current heart rate alert status
bool isTempAlert; | // Current temperature alert status
bool isMotionAlert; | // Current motion alert status
bool lowBattery; | // Current battery alert status

unsigned long hrAlertStart; // Timestamp when heart rate alert began unsigned long tempAlertStart; // Timestamp when temperature alert began unsigned long motionAlertStart; // Timestamp when motion alert began

float accX, accY, accZ; | // Last recorded acceleration values
unsigned long lastUpdate; | // Last data transmission timestamp
bool inEmergency; | // Overall emergency status
};

This structure provides a centralized mechanism for managing alert states while maintaining the temporal context necessary for accurate alert generation. The use of timestamps enables the system to track how long alert conditions have persisted, which is crucial for preventing false alarms.

Alert Generation System
The alert system implements a sophisticated time-based verification approach to ensure the reliability of generated alerts. This is achieved through a combination of threshold definitions and duration requirements:

// Health parameter thresholds
const int HR_MAX = 150; | // Maximum heart rate (bpm)
const int HR_MIN = 40; | // Minimum heart rate (bpm)
const float TEMP_MAX = 40.0; | // Maximum temperature (°C)
const float MOVEMENT_THRESHOLD = 0.5; // Minimum movement detection (G)

// Required duration thresholds
const unsigned long HR_ALERT_TIME = 30000; // Heart rate (30 seconds) const unsigned long TEMP_ALERT_TIME = 180000; // Temperature (3 minutes)
const unsigned long MOTION_ALERT_TIME = 60000; // Motion (1 minute)

The alert generation process follows a three-stage verification approach:
1. Initial Detection: When a parameter exceeds its threshold, the system records the timestamp.
2. 2. Duration Verification: The condition must persist for the specified duration before triggering an alert.
3. 3. Status Reset: When parameters return to normal ranges, the system clears both the alert status and associated timestamp.
For example, the heart rate alert verification is implemented as follows:

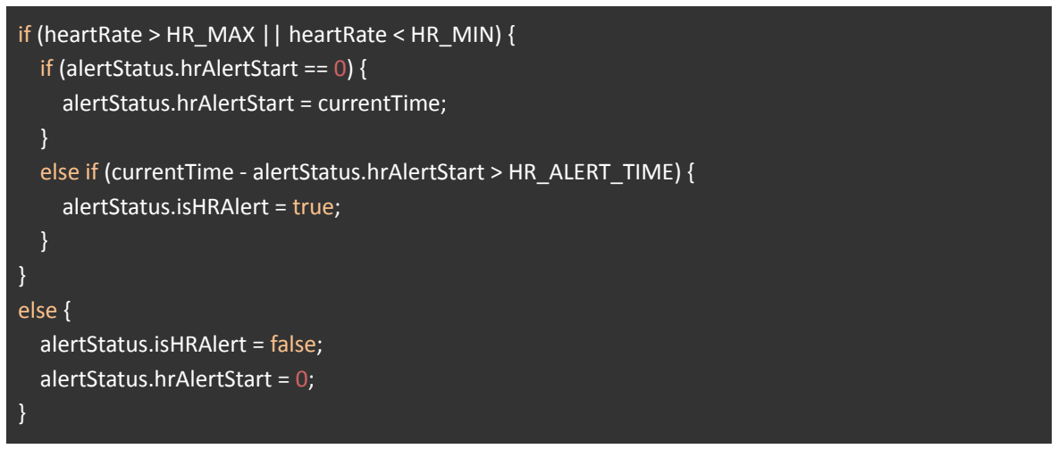
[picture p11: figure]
if (alertStatus.hrAlertStart == 0) { alertStatus.hrAlertStart = currentTime;; alertStatus.isHRAlert = true;; } else { alertStatus.isHRAlert = false; alertStatus.hrAlertStart = 0;

if (heartRate > HR_MAX || heartRate < HR_MIN) {

else if (currentTime - alertStatus.hrAlertStart > HR_ALERT_TIME) {

Adaptive Update Frequency
The system implements an adaptive update frequency mechanism that adjusts data transmission rates based on the firefighter's status:

const unsigned long NORMAL_UPDATE_FREQ = 1000; // Normal mode: 1 second
const unsigned long EMERGENCY_UPDATE_FREQ = 500; // Emergency mode: 0.5 seconds

unsigned long updateInterval = wearableAlert.inEmergency ?
EMERGENCY_UPDATE_FREQ : NORMAL_UPDATE_FREQ;

This design ensures more frequent updates during emergency situations while conserving power during normal operation.
Emergency Status Consolidation
The system maintains a consolidated emergency status that combines all individual alert conditions:

wearableAlert.inEmergency = wearableAlert.isHRAlert ||
wearableAlert.isTempAlert || wearableAlert.isMotionAlert || wearableAlert.lowBattery;

This consolidated status serves multiple purposes:
1. Triggers the increased update frequency
2. Activates emergency notification systems
3. Enables rapid response to any type of emergency condition

Alert Verification Logic
The alert verification system employs a methodical approach to monitoring various health parameters:
1. Heart Rate Monitoring:
a. Tracks both high (>150 bpm) and low (<40 bpm) thresholds
b. Requires 30 seconds of sustained abnormal readings
2. Temperature Monitoring
a. Monitors for elevated temperatures above 40°C b. Requires 3 minutes of sustained elevated readings
3. Motion Detection:
a. Monitors for lack of movement using accelerometer data
b. Triggers alert after 1 minute of no significant motion
4. Battery Status:
a. Monitors battery voltage level
b. Generates immediate alert when battery level falls below 10% This comprehensive approach to alert verification ensures reliable emergency detection while minimizing false alarms through appropriate time-based validation of alert conditions.

### 2.2.6 PCB Design and Iterations

Through the development process, we created four versions of PCBs for both the wearable unit and central unit. Each iteration addressed specific challenges and improvements identified during testing. One significant challenge we encountered involved the voltage regulator selection. Initially, we used the AZ1117CD-3.3TRG1 3.3V regulator, which has a dropout voltage of 1.2V. This high dropout voltage created critical issues when paired with our lithium-ion battery that operates between 3.7V to 4.2V. Given the battery's voltage range and the regulator's dropout voltage of 1.2V, the maximum output voltage possible would be between 2.5V to 3.0V (battery voltage minus dropout voltage), which is significantly below the required 3.3V for proper operation.
This voltage insufficiency manifested in two major problems:
For the wearable unit, the voltage drop prevented the GPS module from establishing proper satellite connections. The GPS module requires a stable 3.3V supply for optimal performance, but with the battery and high-dropout regulator combination, the actual voltage was consistently below the module's minimum operating voltage, compromising its ability to maintain reliable satellite links.
For the central unit, the same voltage issue manifested in the TFT screen's functionality. The screen failed to operate properly due to insufficient voltage caused by the regulator's high dropout rate. This was particularly problematic as the display is crucial for the central monitoring system's operation.
To resolve the voltage regulator issues, we identified a pin-compatible Low-Dropout (LDO) 3.3V regulator with similar physical dimensions but significantly lower dropout voltage. This drop-in replacement allowed us to maintain the existing PCB design while ensuring proper 3.3V output even when the battery voltage drops to 3.7V.
Another significant issue we discovered during testing was related to the ESP32's GPIO strapping pins. Our initial design included a capacitor connected to a GPIO pin that's used during the boot process. This capacitor was preventing the ESP32 from booting properly on power-up, requiring a manual reset button press each time to start the system. We resolved this by removing the capacitor from the GPIO strapping pin in subsequent PCB versions, allowing the system to boot correctly immediately upon receiving power.
A key improvement in later PCB iterations was the addition of dual power source capability. We implemented a design that supports both 5V and 3.3V power sources simultaneously by adding diodes for power source isolation. This enhancement provides several benefits:
- Allows flexible power source selection without PCB modifications
- Enables seamless switching between power sources if one fails

- Reduces the risk of reverse current flow between power sources
- Maintains stable voltage supply even if one source fluctuates
These iterative improvements resulted in final PCB designs that provide reliable operation while maintaining the compact form factor required for integration into firefighter gear.

### 2.3 Subsystem Diagrams & Schematics

Reference Appendix B for individual subsystem schematics as well as full PCB schematic

### 2.3.1 Wearable Unit Subsystem

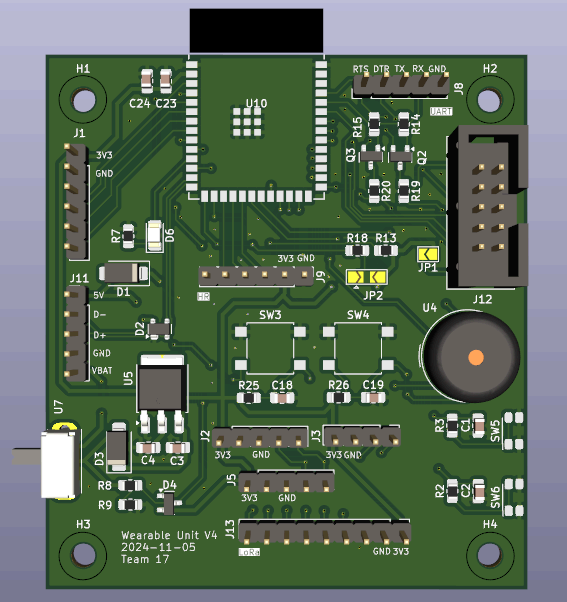
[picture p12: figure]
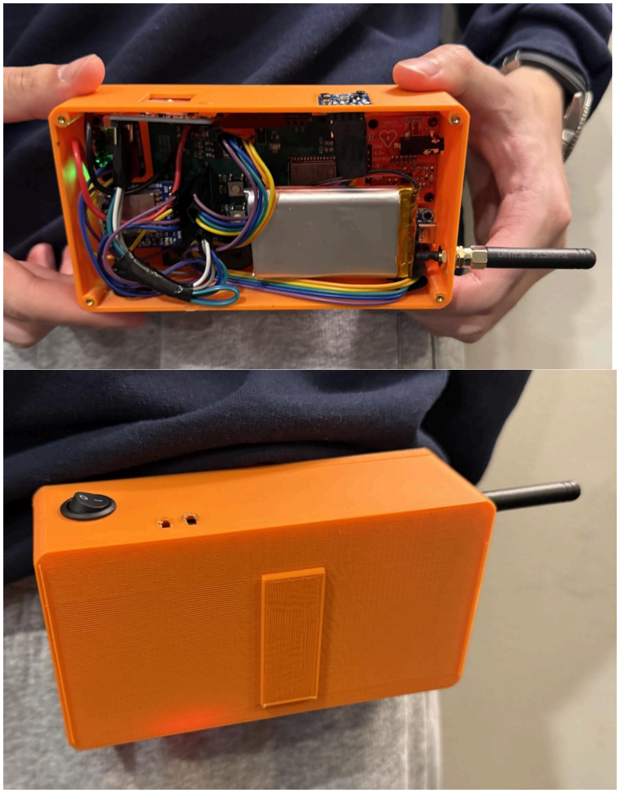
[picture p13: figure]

Figure 2. Wearable Unit PCB design and final product

### 2.3.2 Central Unit Subsystem

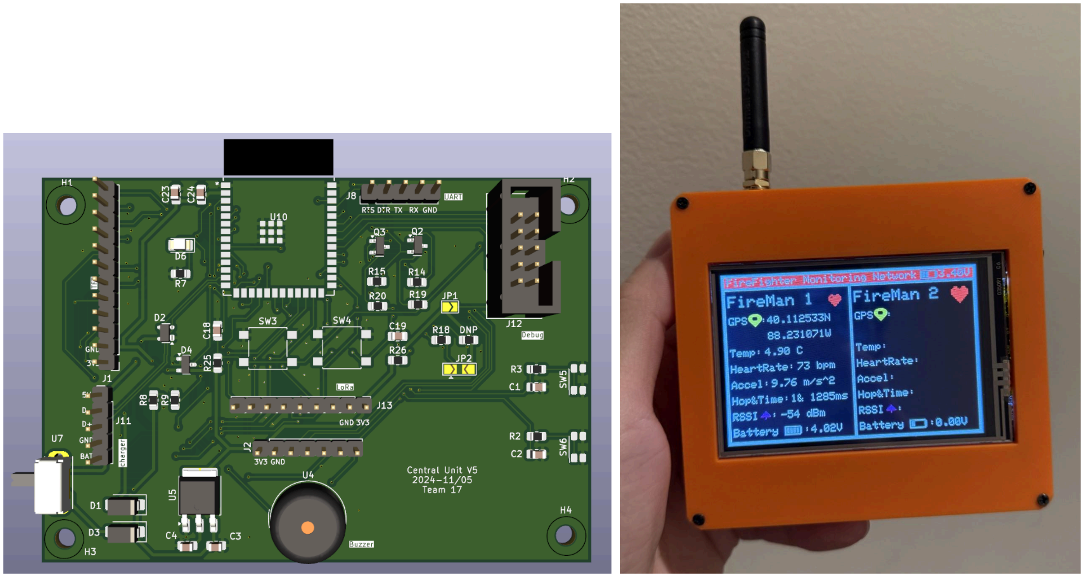
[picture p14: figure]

Figure 3. Central Unit PCB design and final product

### 2.3.2 Power Subsystem

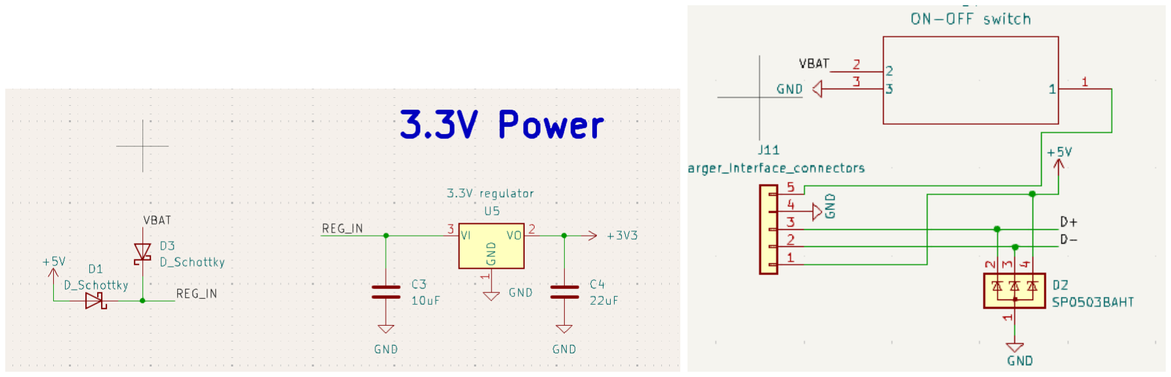
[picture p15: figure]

Figure 4. Power Subsystem Schematic

### 3. Costs

### 3.1 Parts

To test the functionalities of this project, we assembled one fully-functional wearable unit (with sensors) and one central unit, accompanied by two additional “LoRa unit” consisting of a LoRa transceiver, ESP32 microcontroller, and li-ion battery to test the mesh network.

Description | Manufacturer | Part Number | Quantity | Unit Price | Extended Price | Part Link
GPS | SparkFun | MAX-M10S | 1 | $44.95 | $44.95 | Link (https://www.sparkfun.com/products/18037)
LoRa Transceiver | Adafruit | RFM95W | 3 | $19.95 | $59.85 | Link (https://www.adafruit.com/product/3072?gad_source=1)
3.5" TFT LCD Display | Adafruit | HX8357D | 1 | $39.95 | $39.95 | Link (https://www.adafruit.com/product/2050)

Single Lead Heart Rate Sensor | Sparkfun | SEN-12650 | 1 | $21.50 | $21.50 | Link (https://www.digikey.com/en/products/detail/sparkfun-electronics/SEN-12650/5824153?gad_source=1)
Temperature Sensor | Adafruit | BMP 180 | 1 | $9.95 | $9.95 | Link (https://www.adafruit.com/product/1603)
Accelerometer and Gyroscope | Adafruit | LSM6DS032 | 1 | $12.50 | $12.50 | Link (https://www.adafruit.com/product/4692?gad_source=1)
Piezo Buzzer | PDK Corporation | PS1240 | 2 | $1.50 | $3.00 | Link (https://www.adafruit.com/product/160)
Lithium Ion Battery | Adafruit | 3.7V 2000mAh | 3 | $12.50 | $37.50 | Link (https://www.adafruit.com/product/2011)
Micro-Lipo Charger | Adafruit | Micro-Lipo Charger | 3 | $4.90 | $14.70 | Link (https://www.adafruit.com/product/4410)
ESP32-WROOM | Espressif Systems | DOIT ESP32 DEVKIT V1 | 3 | $15.98 | $47.94 | Link (https://www.amazon.com/ESP32-WROOM-32-Development-ESP-32S-Bluetooth-Arduino/dp/B084KWNMM4)

Total Purchased Components Price: $291.84

### 3.2 Labor

As our team is only composed of Computer Engineering students, we only used the annual salary for Computer Engineering students as a reference. According to the Grainger College of Engineering, the average annual starting salary for Computer Engineering students is $109,176, and number of work days in a year is approximately 365*(5/7) ≈ 261 days. Assume a person works 8 hours a day and 261 days per year, then his or her wage per hour is roughly $109,176 / (261*8hr) ≈ $52/hr. As a result, the labor cost of each student will be $52/hr. Over the course of 2 months, we plan to spend an average of 2 hours per day. Thus, the total labor cost will be $52/hr * 2 hr/day * 60 days * 3 students = $18720. Since there is no cost for other resources, we can estimate the total cost of the entire project to be the sum of purchased part and labor: Cost Total = Cost Parts + Cost Labor = $291. 84 + $18, 720 = $19, 011. 84 In total, the entire project will cost around $19,011.84

### 4. Design Verification

Refer to Appendix A for all Tables mentioned below.

### 4.1 Wearable Sensor Subsystem Requirements and Verification

To determine whether the wearable sensor subsystem can measure each status within the tolerance (Table 4.1, row 1), we conducted four tests to verify the accuracy of each sensor data, including heart rate, temperature, motion, and gps location.
First of all, to verify that the heart rate measurement is within the ±0.5 bpm tolerance, we place the wearable device on a person equipped with an Apple Watch to verify the heart rate. The result is shown in Table 4.6, in which the sensor heartbeat measurements fall within the tolerance.
Furthermore, to verify that the temperature measurement is within the ±5°C tolerance, we place a thermometer in a closed box and see if the values are the same for the device and the thermometer. The result is shown in Figure 4.1, in which the difference falls within the tolerance.
Moreover, to verify that the motion measurement is within the ±2m/s

2
tolerance, we place the device on a steady surface and see if the acceleration read is equal to gravity (9.8m/s

2
). The result shows that at steady motion, the reading of the motion sensor is about 10.01m/s

2 and falls within the tolerance.

Last but not least, to verify that the gps location measurement is within the ±20m tolerance, we measure the current coordinate with the phone and validate the values from the gps sensor in the wearable unit. The result is shown in Figure 4.3 and Table 4.7, in which the gps sensor measurement falls within the tolerance.
To determine whether the alert is generated if a firefighter’s heart rate exceeds 150 bpm or falls below 40 bpm for more than 30 seconds (Table 4.1, row 2), we conduct a test to verify. First, we simulate the heart rate of the wearable unit to monitor heart rates while gradually increasing to 160 bpm and decreasing to 35 bpm. Second, we validate that the wearable unit triggers an alert when heart rate exceeds 150 bpm for more than 30 seconds and when it falls below 40 bpm for the same duration. Third, we record response times and ensure alerts are activated correctly. The result of the test shows that the alert is successfully generated when the heart rate is abnormal for 30 seconds, which verifies our requirement.
To determine whether the alert is generated when the temperature exceeds 40°C for more than 3 minutes (Table 4.1, row 3), we conduct a test to verify. First, we place the device near a stove (or controlled heat source) to gradually increase the temperature around the wearable unit. Second, we monitor the wearable unit’s temperature sensor and record readings. Third, we validate that the wearable unit triggers an alert when the temperature exceeds 40°C for more than 3 continuous minutes. The result of the test shows that the alert is successfully generated when the temperature exceeds 40°C for more than 3 minutes.
To determine whether the alert is generated if no significant movement is detected on the firefighter for over 60 seconds (Table 4.1, row 4), we conduct a test to verify. First, we secure the wearable unit to a stationary object or user. Second, we ensure that no movement is detected (within a calibrated margin) for a continuous period of 60 seconds, and verify that an alert is triggered at that moment. Third, we test with varying degrees of movement to ensure the threshold for "significant movement" is correctly calibrated. The result of the test shows that the alert is successfully generated when no significant movement is detected on the firefighter for over 60 seconds.

### 4.2 Central Monitoring Hub Subsystem Requirements and Verification

To determine whether the central unit display should be able to visualize the firefighter data holistically (Table 4.2, row 1), we have two wearable devices sending out simulated information to the central unit to verify it is able to display the firefighters' data holistically. After the test, the central unit can display all the data on the screen, which verifies our requirements.
To determine whether the central unit sends out a critical alert and change of LED color when abnormal activities occur (Table 4.2, row 2), we manually input data with different conditions (normal, abnormal, dangerous) to the subsystem and observe whether the alert is turned on or off. After the test, the central unit can change the text color of those abnormal data from white to red and activate its buzzer, which verifies our requirements.

### 4.3 Power Subsystem Requirements and Verification

To determine whether wearable and central units can send alerts when the battery is low (below 10%) to the central unit (Table 4.3, row 1), we charge the device to 15% and operate the device until the battery drops down to 10%, which is measured with a multimeter, to verify if the alert is sent. The result shows that the buzzer is activated and an alert is sent to the central unit when the devices have low battery, which verifies our requirement.
To determine whether both the wearable unit and the central unit can last at least 2 hours on a single charge under typical operation conditions (temperatures above 30°C) (Table 4.3, row 2), we use the serial monitor to print out the voltage read from our battery voltage reader to verify both the wearable unit and central unit has battery life longer than 2 hours. The result is shown in Figure 4.2, where both devices have more than 50% voltage after 2.5 hours of operation.

### 4.4 User Interface Subsystem Requirements and Verification

To determine whether there’s a custom-designed graphical user interface (GUI) for the 3.5" TFT touch screen (Table 4.4, row 1), we visually inspect the GUI layout on the actual 3.5" screen and verify if all the data received are the same from the wearable units by printing out those data in Serial monitor. The result shows that the GUI can display all the data with a customized design.
To determine whether there are real-time data visualization components (graphs, charts, status indicators) (Table 4.4, row 2), we simulate data input for graphs, charts, and status indicators and verify real-time updates of visualizations. Then, we test different data scenarios (normal, critical, edge cases) and measure and verify update frequency matches the requirements. The results show that the real-time data are received and displayed on the user interface.
To determine whether there is an alert management system with visual and auditory cues (Table 4.4, row 3), we trigger various alert conditions and verify visual cues appear correctly on screen. Then, we test auditory alerts for proper sound and volume and confirm alert prioritization works as designed. The results show that the alert is triggered when abnormal activities occur and the text color is changed to red for abnormal status.

### 4.5 Mesh Network Integration Subsystem Requirements and Verification

To determine whether data transmission time from any firefighter to the central unit exceeds 15 seconds and the communication range is at least 600m in open areas and 250m in urban environments (Table 4.5, row 1), we first calculate the differences between the wearable unit packet sent time using GPS time vs the central unit received time to verify the communication time is within 15 seconds. The result shows an average of around 2 seconds of transmission time between 3 nodes. Next, we conduct two tests, one in an open area and one in an area with buildings, and measure the distance between nodes to meet the requirement. Then, we test if each node can receive data from each other. The result shows that we meet the requirement in which the nodes are capable of receiving data from the required range.
To determine whether a mesh network is created so that even if a wearable is not directly in range to the central unit it can hop between the other wearable that’s in range to connect to the central unit (Table 4.5, row 2), we set up a test environment with multiple wearable units and obstacles to force multi-hop routing and gradually move units out of direct range of the central hub. Then, we verify data from out-of-range units successfully reaches the central hub via other units and use network visualization tools to confirm the mesh topology. Last, we simulate node failures to test self-healing capabilities and measure and compare latency for direct vs multi-hop communications. The result shows that the mesh network is successfully set up.

### 5. Conclusion

### 5.1 Accomplishments

The Firefighter Health Monitoring Network project has successfully achieved its primary objectives, resulting in a complete and functional product. The wearable units seamlessly integrate all four sensors -heart rate, accelerometer, temperature, and GPS - enabling comprehensive, real-time monitoring of firefighter health and location. The system effectively generates alerts based on predefined thresholds, both on the wearable units and the central monitoring hub, ensuring rapid response to potential health emergencies.
Notably, the system meets or exceeds all the high-level requirements outlined at the project's inception. The power supply for the wearable units sustains operation for more than 2 hours on a single charge, even in demanding firefighting conditions above 30°C. The LoRa-based mesh network enables reliable data transmission between wearable nodes and the central unit, automatically routing data through multiple hops when direct communication is hindered. Furthermore, the sensors achieve the required accuracy levels, providing trustworthy data for informed decision-making.
The central monitoring hub features a well-designed, user-friendly display that presents real-time health data and alerts for each firefighter. This intuitive interface empowers incident commanders to quickly assess the situation and make critical decisions to ensure the safety and well-being of their team.

### 5.2 Ethical considerations

Data Privacy and Security:

According to the ACM Code of Ethics, members should "respect the privacy of others" and "honor confidentiality" [8]. Monitoring firefighters' health data involves collecting sensitive personal information such as heart rate, surrounding temperature, and potentially location data. Any breach of this data could lead to privacy violations.
Solution: The team implemented strict access controls, ensuring that only authorized personnel (e.g., the incident commander) can view the data.
Informed Consent:
Firefighters must be fully informed about what data is being collected, how it will be used, and their rights to privacy under the IEEE Code of Ethics (Clause 1). This includes consent not only for data collection during their active duty but also how their data may be used in post-incident reviews. Solution: The team ensured that firefighters provide informed consent before wearing the monitoring devices. Clear and accessible explanations were offered regarding what data will be collected, why, and how it will be protected.

### 5.3 Future work

To further enhance the Firefighter Health Monitoring Network, the team has identified several areas for future development:
1. Support more nodes (>10 nodes) to extend LoRa communication range (~1km)
2. Design a more compact enclosure to improve wearability
3. Develop a user interface on the wearable unit for more intuitive visuals
4. Implement more advanced algorithms for analyzing heart rate data to detect a broader range of symptoms
By addressing these future improvements, the Firefighter Health Monitoring Network can become an even more robust, user-friendly, and effective tool for ensuring the safety and well-being of firefighters in the line of duty.

### References

[1] Coca, A., Williams, W. J., Roberge, R. J., & Powell, J. B. (2010). Effects of fire fighter protective ensembles on mobility and performance. Applied Ergonomics, 41(4), 636-641.
[2] Horn, G. P., Blevins, S., Fernhall, B., & Smith, D. L. (2013). Core temperature and heart rate response to repeated bouts of firefighting activities. Ergonomics, 56(9), 1465-1473.
[3] “IEEE Code of Ethics,” IEEE, https://www.ieee.org/about/corporate/governance/p7-8.html Accessed 19 Sept. 2024.
[4] Kales, S. N., Soteriades, E. S., Christophi, C. A., & Christiani, D. C. (2007). Emergency duties and deaths from heart disease among firefighters in the United States. New England Journal of Medicine, 356(12), 1207-1215.
[5] M. Spotnitz, "Simulation of capacity fade in lithium-ion batteries," Journal of Power Sources, vol. 113, no. 1, pp. 72-80, 2003. https://doi.org/10.1016/S0378-7753(02)00490-1. Accessed 3 Oct. 2024.
[6] Rodríguez-Marroyo, J. A., Villa, J. G., López-Satue, J., Pernía, R., Carballo, B.,
García-López, J., & Foster, C. (2011). Physical and thermal strain of firefighters according to the firefighting tactics used to suppress wildfires. Ergonomics, 54(11), 1101-1108.
[7] Smith, D. L., Haller, J. M., Dolezal, B. A., Cooper, C. B., & Fehling, P. C. (2018). Evaluation
of a wearable physiological status monitor during simulated fire fighting activities. Journal of Occupational and Environmental Hygiene, 15(2), 121-131.
[8] “The Code Affirms an Obligation of Computing Professionals to Use Their Skills for the Benefit of Society.” Code of Ethics, www.acm.org/code-of-ethics. Accessed 19 Sept. 2024.

### Appendix A Figures and Tables

Table 4.1 Wearable Sensor Subsystem Requirements and Verifications
Requirement | Verification | Verification status (Y or N)
1. Sensors should measure each status within the tolerance a. Measures heart rate with an accuracy of ±5 bpm. b. Measures temperature with an accuracy of ±1.0°C. c. Detects motion with a resolution of ±2m/s2. d. Detects location with a tolerance of ±20m. | 1. Place the device on a person equipped with Apple Watch and validate the heartbeat 2. Place a thermometer in a closed box and see if the values are the same for the device and the thermometer 3. Place the device on a steady surface and see if the acceleration read is equal to gravity (9.8m/s2) 4. Measure the current coordinate with phone and validate the values from the gps sensor in the wearable unit | Y
2. Alert is generated if a firefighter’s heart rate exceeds 150 bpm or falls below 40 bpm for more than 30 seconds. | 3. Simulate the heart rate of the wearable unit to monitor heart rates while gradually increasing to 160 bpm and decreasing to 35 bpm. 4. Validate that the wearable unit triggers an alert when heart rate exceeds 150 bpm for more than 30 seconds and when it falls below 40 bpm for the same duration. 5. Record response times and ensure alerts are activated correctly. | Y
3. Alert is generated when the temperature exceeds 40°C for more than 3 minutes. | 4. Place the device nearby a stove (or controlled heat source) to gradually increase the temperature around the wearable unit. 5. Monitor the wearable unit’s temperature sensor and record readings. 6. Validate that the wearable unit triggers an alert when the | Y

| temperature exceeds 40°C for more than 3 continuous minutes.
4. Alert is generated if no significant movement is detected on the firefighter for over 60 seconds. | 1. Secure the wearable unit to a stationary object or user. 2. Ensure that no movement is detected (within a calibrated margin) for a continuous period of 60 seconds, and verify that an alert is triggered at that moment. 3. Test with varying degrees of movement to ensure the threshold for "significant movement" is correctly calibrated. | Y

Table 4.2 Central Monitoring Hub Subsystem Requirements and Verifications

Requirement | Verification | Verification status (Y or N)
1. The central unit display should be able to visualize the firefighter data holistically | 1. Have two wearable device sending out simulated information to the central unit to verify it is able to display the firefighters data holistically | Y
2. Send out a critical alert and change of LED color when abnormal activities occur | 1. Manually input data with different conditions (normal, abnormal, dangerous) to the subsystem and observe whether the alert is turned on or off | Y

Table 4.3 Power Subsystem Requirements and Verifications

Requirement | Verification | Verification status (Y or N)
1. Wearable units should send alerts when the | 1. Charge the device to 15% and operate the device until the battery | Y

battery is low (below 10%) to the central unit. | drops down to 10% measuring with a multimeter to verify if the alert is sent.
2. Both the wearable unit and the central unit should last at least 2 hours on a single charge under typical operation conditions (temperatures above 30°C). | 1. Simulate the sensor readings using ADALM2000, record the battery voltage every 5 mins to verify both the wearable unit and central unit has battery life longer than 2 hours. | Y

Table 4.4 User Interface Subsystem Requirements and Verifications

Requirement | Verification | Verification status (Y or N)
1. Custom-designed graphical user interface (GUI) for the 3.5" TFT touch screen | 1. Visually inspect GUI layout on the actual 3.5" screen 2. Verify if all the data received are the same from the wearable units by printing out those data in Serial monitor | Y
2. Real-time data visualization components (graphs, charts, status indicators) | 1. Simulate data input for graphs, charts, and status indicators 2. Verify real-time updates of visualizations 3. Test different data scenarios (normal, critical, edge cases) 4. Measure and verify update frequency matches requirements | Y

3. Alert management
system with visual and
auditory cues
5. Trigger various alert
conditions
6. Verify visual cues
appear correctly on
screen
7. Test auditory alerts for proper sound and
volume
8. Confirm alert
prioritization works as
designed
9. Test alert
acknowledgment and
dismissal functionality

Y

Table 4.5 Mesh Network Integration Subsystem Requirements and Verifications

Requirement | Verification | Verification status (Y or N)
1. Data transmission time from any firefighter to the central unit shall not exceed 15 seconds | 1. Calculate the differences between the wearable unit packet sent time using gps time vs the central unit received time to verify the communication time is within 15 seconds. | Y
2. Create its mesh network so even if a wearable is not directly in range to the central unit it can hop between the other wearable that’s in range to connect to the central unit | 1. Set up a test environment with multiple wearable units and obstacles to force multi-hop routing. 2. Gradually move units out of direct range of the central hub. 3. Verify data from out-of-range units successfully reaches the | Y

c

e

n

t

r

al h

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
s. 4. Use n
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
aliz

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
y. 5. Simulate
n

o

d

e

f

ailu

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
elf-

h

e

alin

g
c

a

p

a

bilitie

s. 6. Measure an
d

c

o

m

p

a

r

e latency for direct vs multi-hop communications.

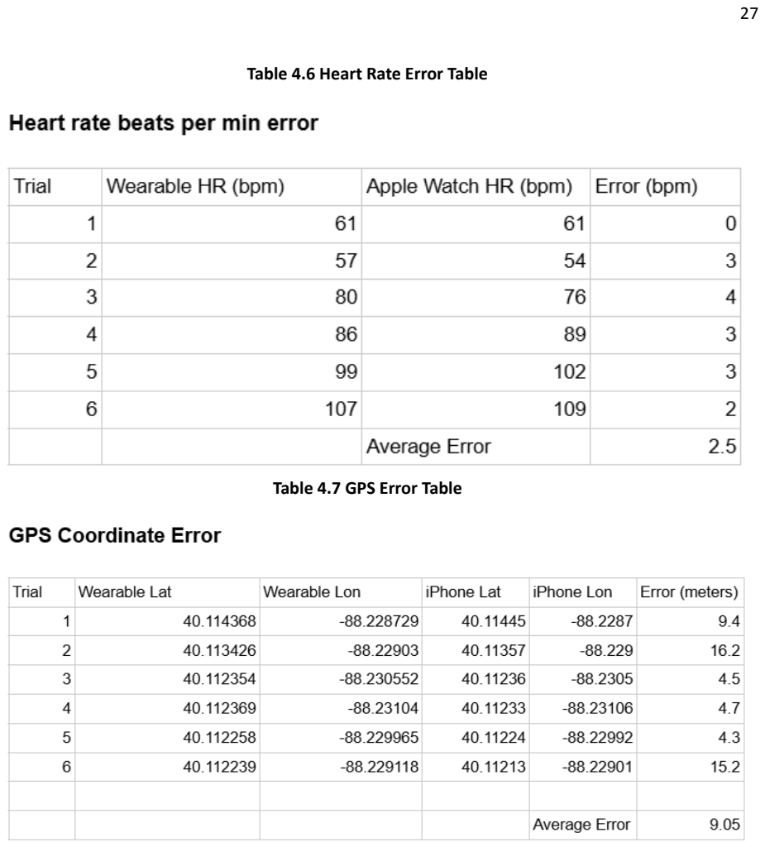
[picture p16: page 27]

Table 4.6 Heart Rate Error Table

Table 4.7 GPS Error Table

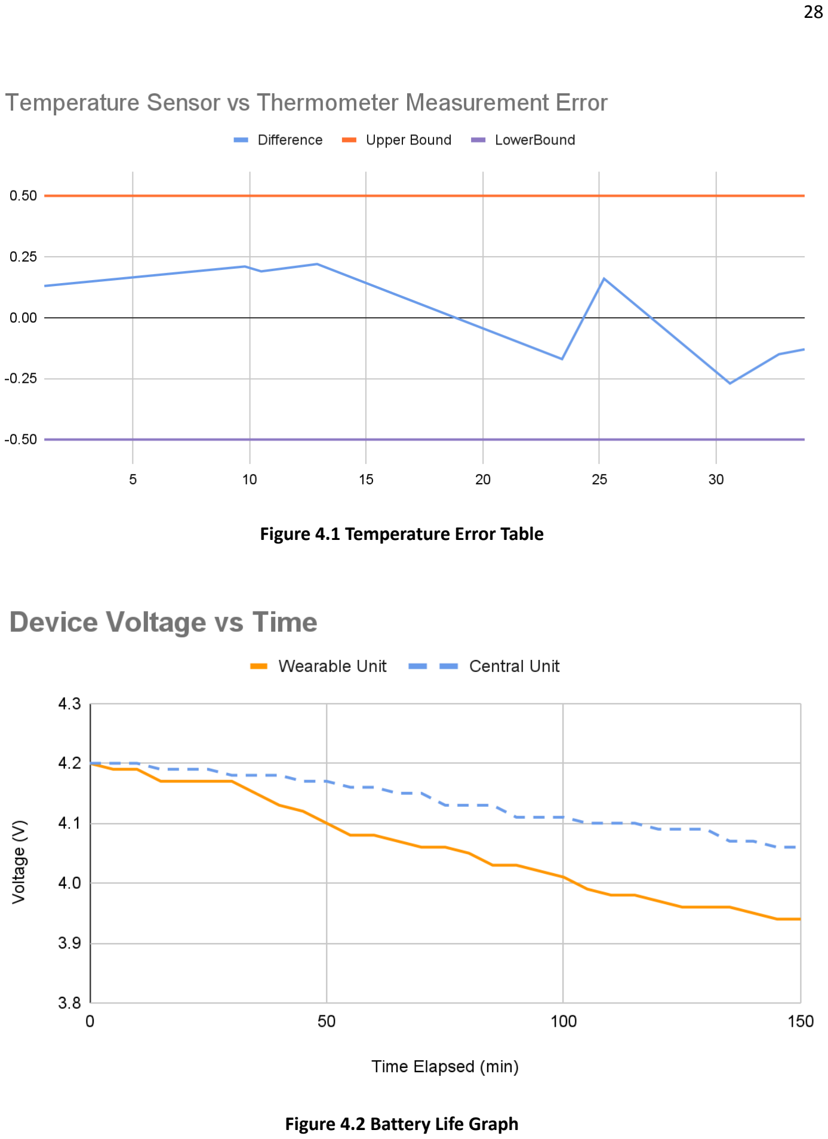
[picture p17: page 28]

Figure 4.1 Temperature Error Table

Figure 4.2 Battery Life Graph

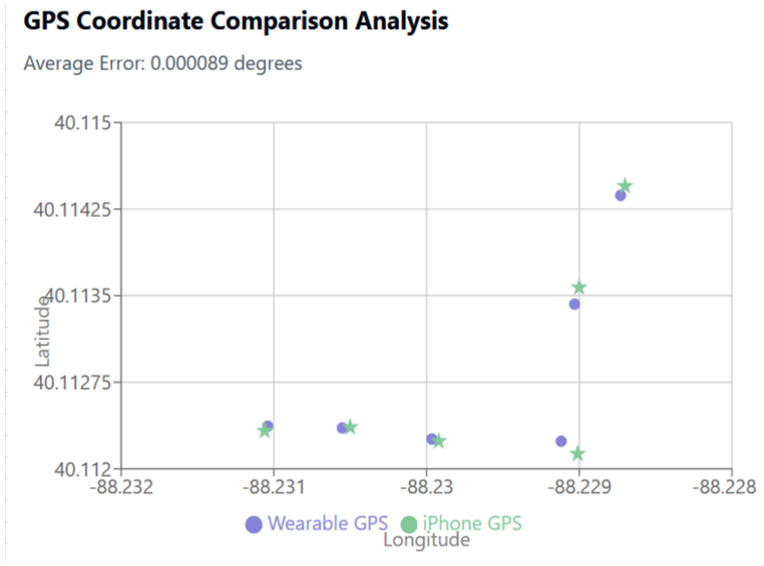
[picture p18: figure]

Figure 4.3 GPS Coordinate Comparison Graph

### Appendix B Individual subsystem schematics and Full PCB schematic

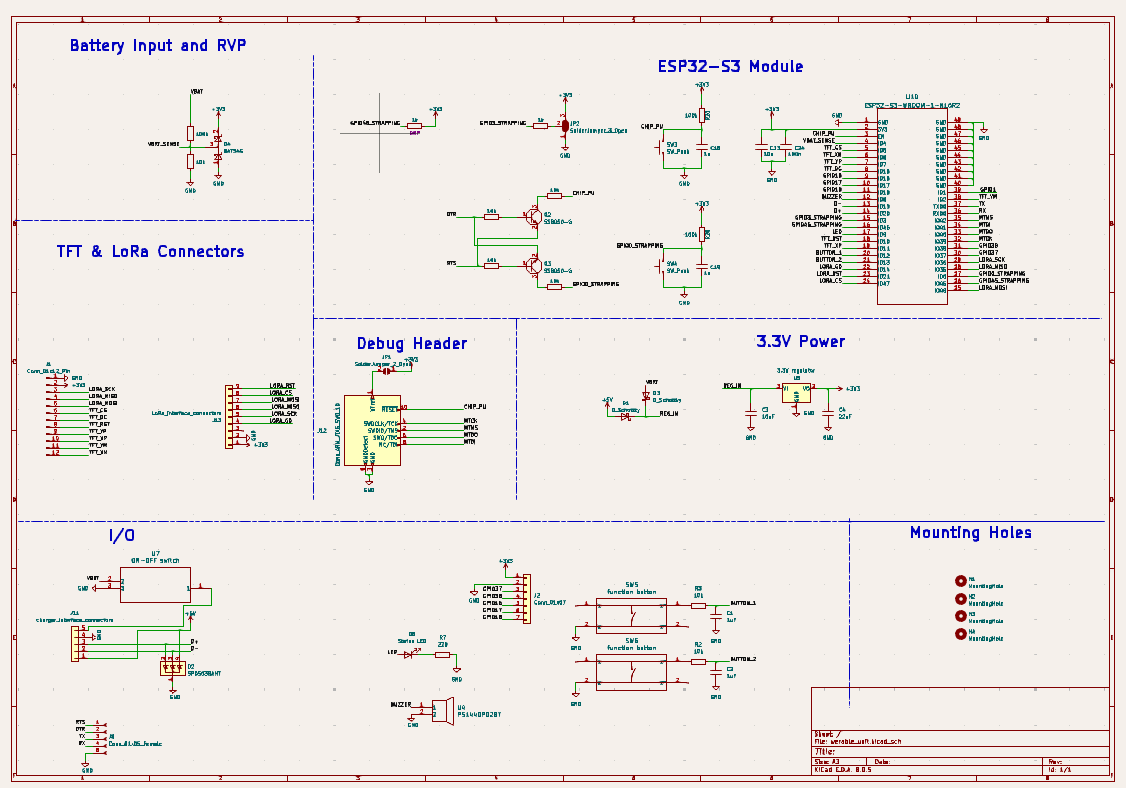
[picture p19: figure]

Figure 5. Wearable Unit Schematics

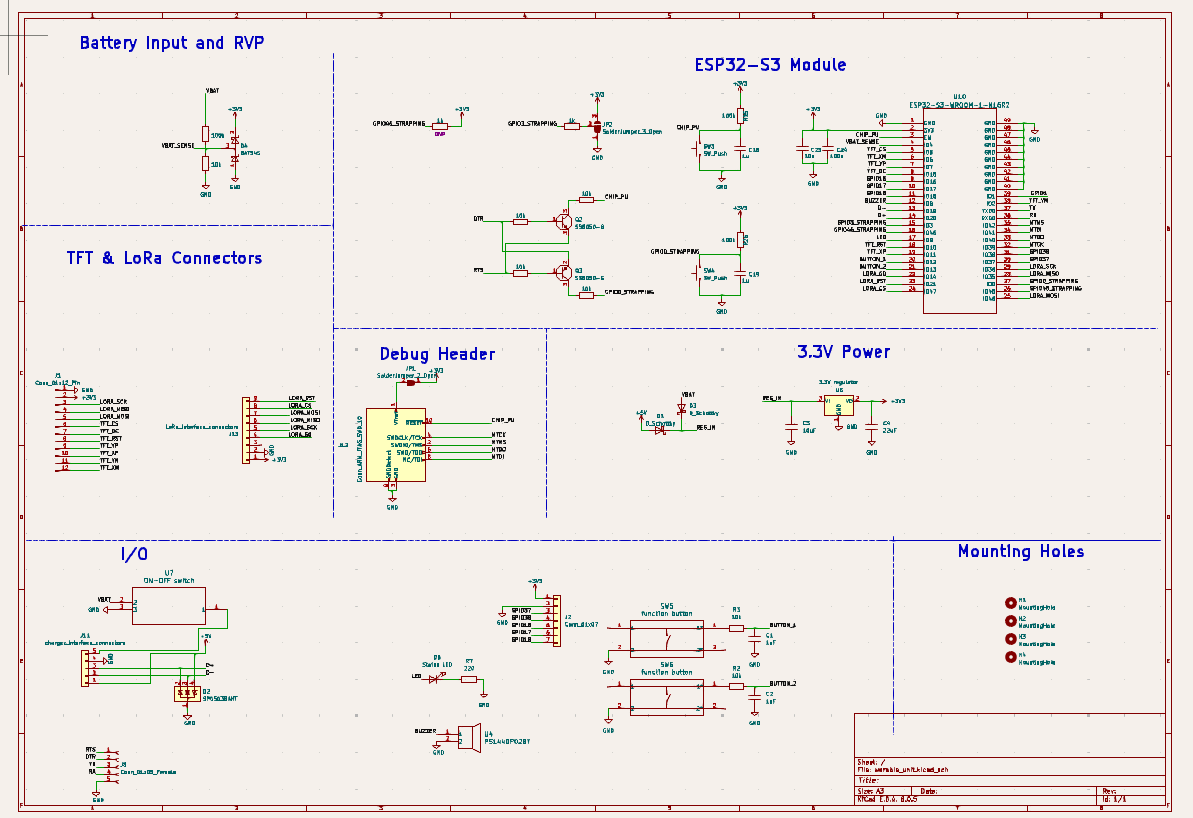
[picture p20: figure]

Figure 6. Central Unit Schematics

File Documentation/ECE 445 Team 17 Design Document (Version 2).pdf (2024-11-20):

## FIREFIGHTER HEALTH MONITORING NETWORK

## ECE 445 DESIGN DOCUMENT - FALL 2024

### Team 17

### Bryan Chang (chchang9)

### Kevin Huang (kuanwei2)

### Steven Y M Chang (sychang5)

### TA: Surya Vasanth

### Professor: Cunjiang Yu

# Contents

2.3.2 Resilience of Mesh Network Communication to Maximum Allowable Delay........28

## 1. Introduction

### 1.1 Problem

Firefighters operate in extremely hazardous environments where their health and safety are

constantly at risk. Current methods of monitoring firefighter health during active duty are

limited, often relying on periodic check-ins or self-reporting. This can lead to delayed responses

to health emergencies, such as heat exhaustion, overexertion, or cardiac events. Incident

commanders lack real-time, comprehensive health data on their team, making it challenging to

make informed decisions about resource allocation and firefighter safety.

Research supports the critical nature of this problem:

- Cardiovascular events: Studies have shown that firefighters are at a significantly higher

risk of on-duty cardiovascular events compared to other professions. Kales et al. (2007)

found that 45% of on-duty firefighter fatalities were due to sudden cardiac death,

highlighting the need for continuous cardiac monitoring [4].

- Heat stress: A study by Horn et al. (2013) demonstrated that core body temperature can

rise to dangerous levels during firefighting activities, with some firefighters reaching

temperatures above 38.5°C (101.3°F), which is associated with heat exhaustion and

cognitive impairment [2].

- Physical exertion: Rodríguez-Marroyo et al. (2012) reported that firefighters routinely

work at 60-95% of their maximum heart rate during emergency operations, indicating

high levels of physiological stress that require monitoring [6].

- Limitations of current monitoring: Coca et al. (2011) highlighted the inadequacy of

periodic vital sign checks, noting that they fail to capture the dynamic nature of

physiological responses during firefighting activities [1].

- Decision-making challenges: Smith et al. (2016) emphasized the importance of real-time

physiological data for incident commanders to make informed decisions about crew

rotation and resource allocation, which current systems do not adequately provide [7].

These research findings underscore the urgent need for a comprehensive, real-time health

monitoring system for firefighters that can track vital signs such as ECG/EKG and movement

patterns through accelerometry. Such a system would enable early detection of potential health

emergencies and support more informed decision-making by incident commanders, ultimately

enhancing firefighter safety and operational effectiveness.

### 1.2 Solution

We propose the development of a "Firefighter Health Monitoring Network" - a system of

wearable devices integrated into firefighters' gear that continuously monitors vital signs and

environmental conditions. The system uses a mesh network of ESP32-based devices to transmit

real-time health data to a central monitoring hub. This allows incident commanders to have

immediate, comprehensive awareness of their team's health status, enabling quick

decision-making and potentially life-saving interventions.

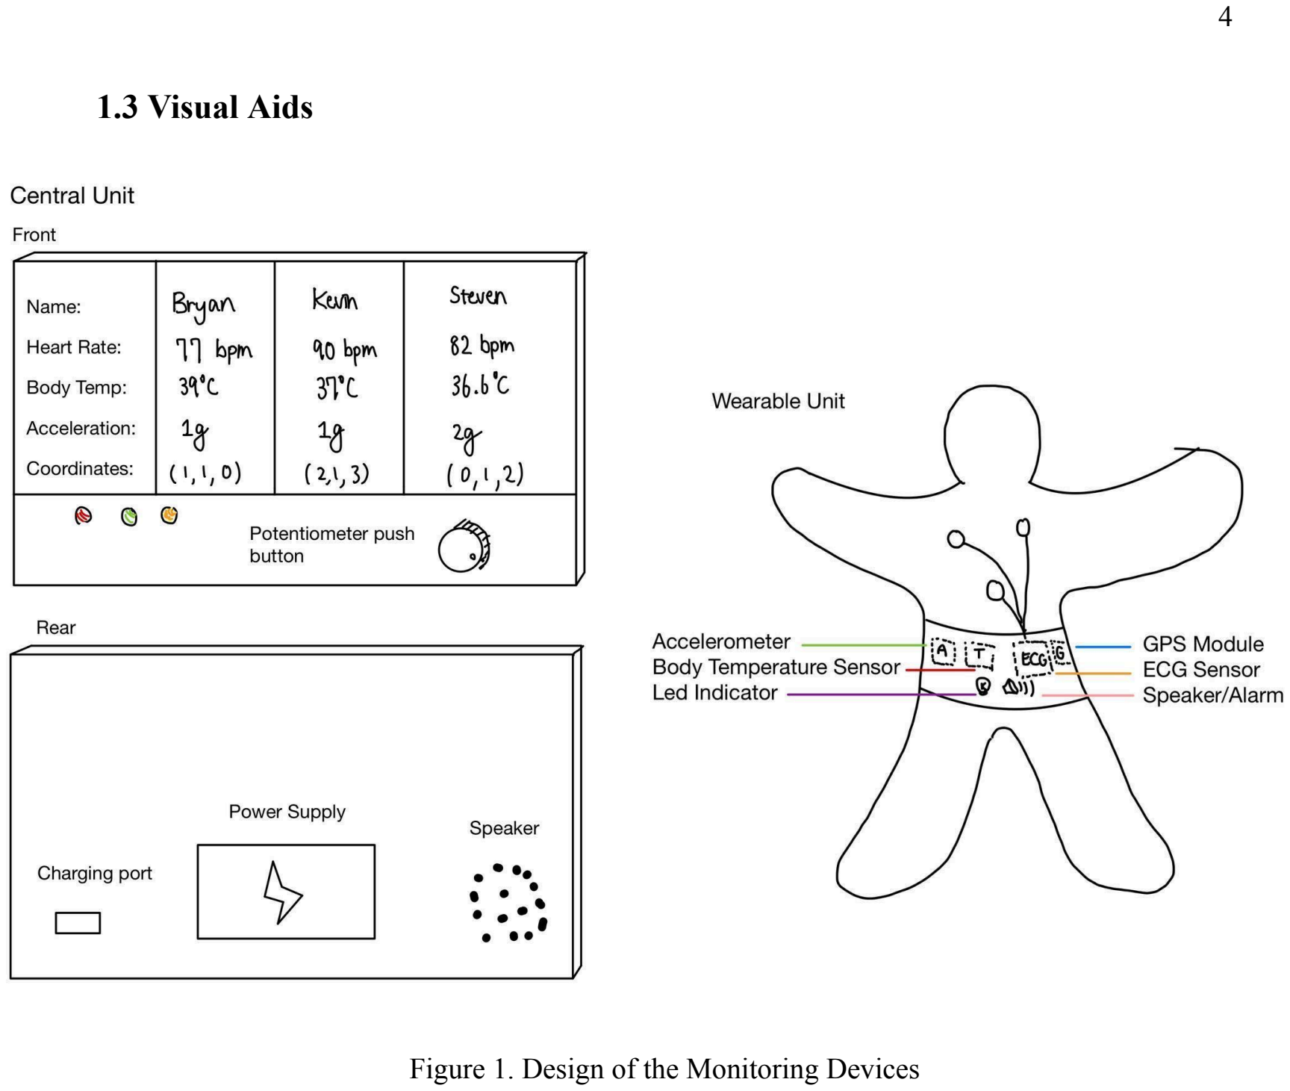
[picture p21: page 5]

### 1.3 Visual Aids

Figure 1. Design of the Monitoring Devices

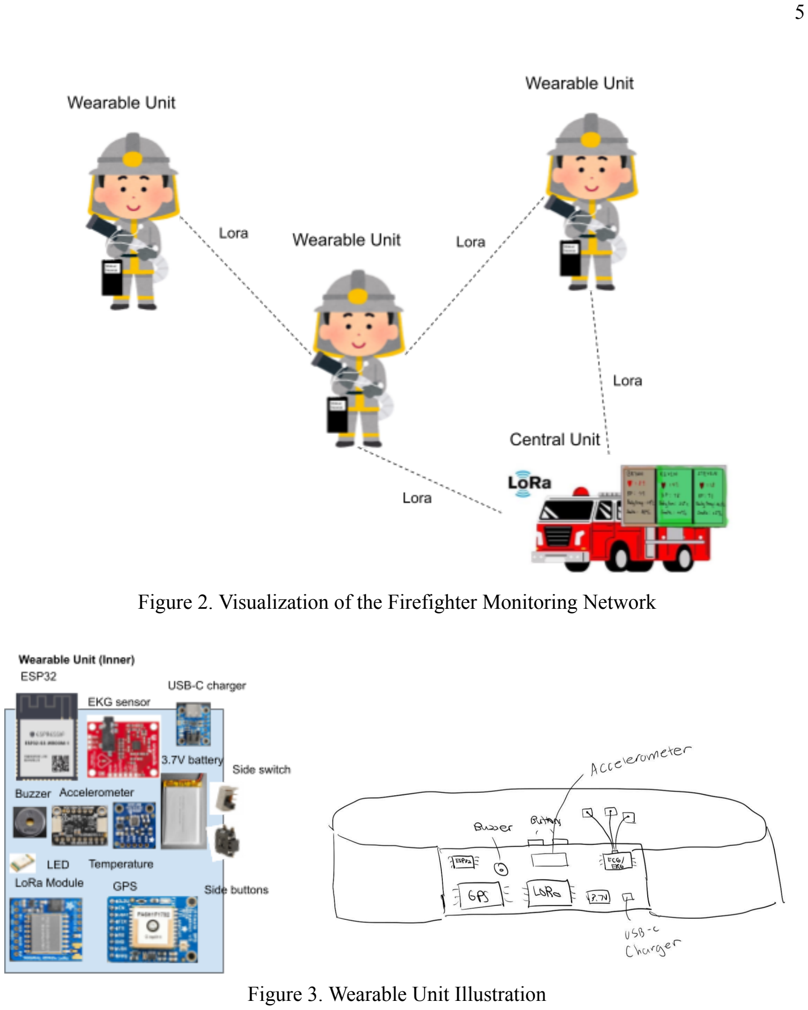
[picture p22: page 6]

Figure 2. Visualization of the Firefighter Monitoring Network

Figure 3. Wearable Unit Illustration

### 1.4 High-Level Requirements

1. The system shall continuously monitor and transmit the following data with 90%

accuracy and operate on a single charge for at least 2 hours in typical fire fighting

conditions above 30°C.

a. ECG/EKG Data
b. GPS Location
c. Motion Data
d. Surrounding temperature Data
2. The system shall generate buzzer alerts on the wearable unit and central monitor within

10 seconds of abnormal detections based on thresholds on data from sensors:

a. ECG/EKG Data
i. Heart rates <40 bpm or >150 bpm sustained for >30 seconds, or upon

detection of specified arrhythmias.

b. Motion Data
i. No significant motion detected for >60 seconds
c. surrounding temperature Data
i. Temperature exceeds 40°C for more than 3 minutes
3. The mesh network shall maintain connectivity in challenging environments with a

minimum range of 300 meters in urban settings and 1 km in open areas, using LoRa

technology. The system shall automatically route data through multiple hops

(firefighter-to-firefighter) to reach the central unit when direct communication is not

possible. End-to-end data transmission time from any firefighter to the central unit shall

not exceed 15 seconds, even when relaying through multiple nodes.

## 2. Design

### 2.1 Block Diagram

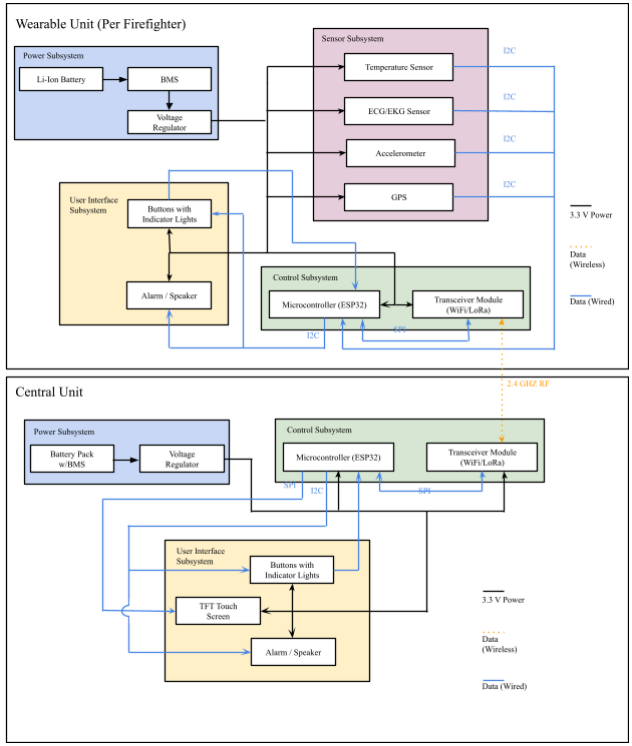
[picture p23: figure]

Figure 4. Block Diagram

### 2.2 Subsystem Overview and Requirements

### 2.2.1 Wearable Sensor Subsystem

This subsystem is responsible for continuously collecting real-time health and environmental

data from individual firefighters. The sensors track vital signs like heart rate, surrounding

temperature, and motion. The data is sent to the mesh network of the ESP32 and the central hub

via reliable communication methods ESP-MESH and LoRa. The enclosure will be designed

using 3D Computer-aided design software and printed out using a 3D printer with Polylactic acid

material (PLA). Although PLA might have lower heat-resistance, other material like

Polyetheretherketone (PEEK) could be replaced with the same design but with higher cost. For

the purpose of this project, we will prioritize the design.

1. ESP32 Microcontroller
- Processor:
i. Dual-core Xtensa LX6 microprocessor

ii. Clock speed: 240 MHz

iii. Performance: Minimum 600 DMIPS (Dhrystone MIPS)

- Memory:
i. RAM: Minimum 520 KB SRAM

ii. Flash memory: Minimum 4 MB

iii. Support for external SPI flash up to 16 MB

- Peripherals:
i. The ESP32 must provide sufficient interfaces and GPIO pins to support

simultaneous connection of:

1. ECG/EKG Sensor

2. Temperature Sensor
3. Accelerometer/Gyroscope
4. GPS Module
5. LoRa Module
6. Piezo Buzzer

ii. Key interface requirements:

1. At least 1 ADC channel for ECG/EKG sensor
2. I2C interface for temperature and accelerometer/gyroscope sensors
3. UART interface for GPS module
4. SPI interface for LoRa module
5. 1 additional GPIO for the buzzer
6. Total GPIO pins required: Minimum 14
- Power Management:
i. Deep sleep current: < 10 μA

ii. Light sleep current: < 800 μA

iii. Operating voltage: 3.0V to 3.6V

2. Electrocardiogram Sensor (ECG/EKG Sensor)
- Measures heart rate with a range of 40-220 bpm and an accuracy of ±2 bpm.
- Alert is generated if a firefighter’s heart rate exceeds 150 bpm or falls below 40

bpm for more than 30 seconds. These thresholds account for both sustained

tachycardia and bradycardia, indicating potential danger to the firefighter’s health.

3. Temperature Sensor
- Measures temperature from 30°C to 45°C with an accuracy of ±0.1°C

- Alert is generated when temperature exceeds 40°C for more than 3 minutes
4. Accelerometer for Motion Detection
- Detects motion with a resolution of ±2g for accelerometers
- Alert is generated if no significant movement is detected for over 60 seconds,

which may indicate that the firefighter has fallen or is immobilized.

5. GPS Module
- Detects location with a tolerance of ±10m.
- In emergency situations where one or more alerts have been triggered, the update

frequency increases from every 30 seconds to every 5 seconds.

6. LoRa Module for Extended Communication
- LoRa mesh network must ensure a communication range of at least 1 km in open

areas and 300 meters in urban or obstructed environments

- The system shall automatically route data through multiple hops

(firefighter-to-firefighter) to reach the central unit when direct communication is

not possible.

- End-to-end data transmission time from any firefighter to the central unit shall not

exceed 15 seconds, even when relaying through multiple nodes.

7. Buzzer to send out a critical alert to the watch commander
8. Lithium-Ion Rechargeable Battery
- The system should last at least 2 hours on a single charge under typical operation

conditions (temperatures above 30°C)

9. Buttons for Simple Setting Configuration
Requirements | Verification

Wearable unit measures the surrounding temperature, heart rate, acceleration, and location of the user and sends it to the Central Monitoring Hub subsystem. ● Measures heart rate with an accuracy of ±2 bpm. ● Measures temperature with an accuracy of ±0.1°C. ● Detects motion with a resolution of ±2g. ● Detects location with a tolerance of ±10m. | 1. Place a thermometer in a closed box and see if the values are the same for the device and the thermometer 2. Place the device on a person equipped with Apple Watch and validate the heartbeat count 3. Place the device on a steady surface and see if the acceleration read is equal to gravity (9.8m/s² ) 4. Measure the current coordinate with phone and validate the values from the gps sensor in the wearable unit 5. Output the readings to a terminal and confirm that the central unit is reading the values in real time
Alert is generated if a firefighter’s heart rate exceeds 150 bpm or falls below 40 bpm for more than 30 seconds. These thresholds account for both sustained tachycardia and bradycardia, indicating potential danger to the firefighter’s health. | 1. Simulate the heart rate readings using ADALM2000 2. Set the wearable unit to monitor heart rates while gradually increasing to 160 bpm and decreasing to 35 bpm. 3. Validate that the wearable unit triggers an alert when heart rate exceeds 150 bpm for more than 30 seconds and when it falls below 40 bpm for the same duration. 4. Record response times and ensure alerts are activated correctly.
Alert is generated when the temperature exceeds 40°C for more than 3 minutes. | 1. Place the device nearby a stove (or controlled heat source) to gradually increase the temperature around the wearable unit. 2. Monitor the wearable unit’s temperature sensor and record readings. 3. Validate that the wearable unit triggers an alert when the temperature exceeds 40°C for more than 3 continuous minutes.
Alert is generated if no significant movement is detected on the firefighter for over 60 seconds. | 1. Secure the wearable unit to a stationary object or user. 2. Ensure that no movement is detected (within a calibrated margin) for a

| continuous period of 60 seconds, and verify that an alert is triggered at that moment. 3. Test with varying degrees of movement to ensure the threshold for "significant movement" is correctly calibrated.
In emergency situations where one or more alerts have been triggered, the GPS update frequency increases from every 30 seconds to every 5 seconds. | 1. Trigger one of the alerts (heart rate, temperature, or motion) while monitoring the GPS update frequency. 2. Have the person wearing the monitoring unit be continuously moving. 3. Record the GPS update intervals to verify that the unit updates every 5 seconds during an alert condition.
Reset the device if the button is pressed | 1. Press the button and verify the device restarts

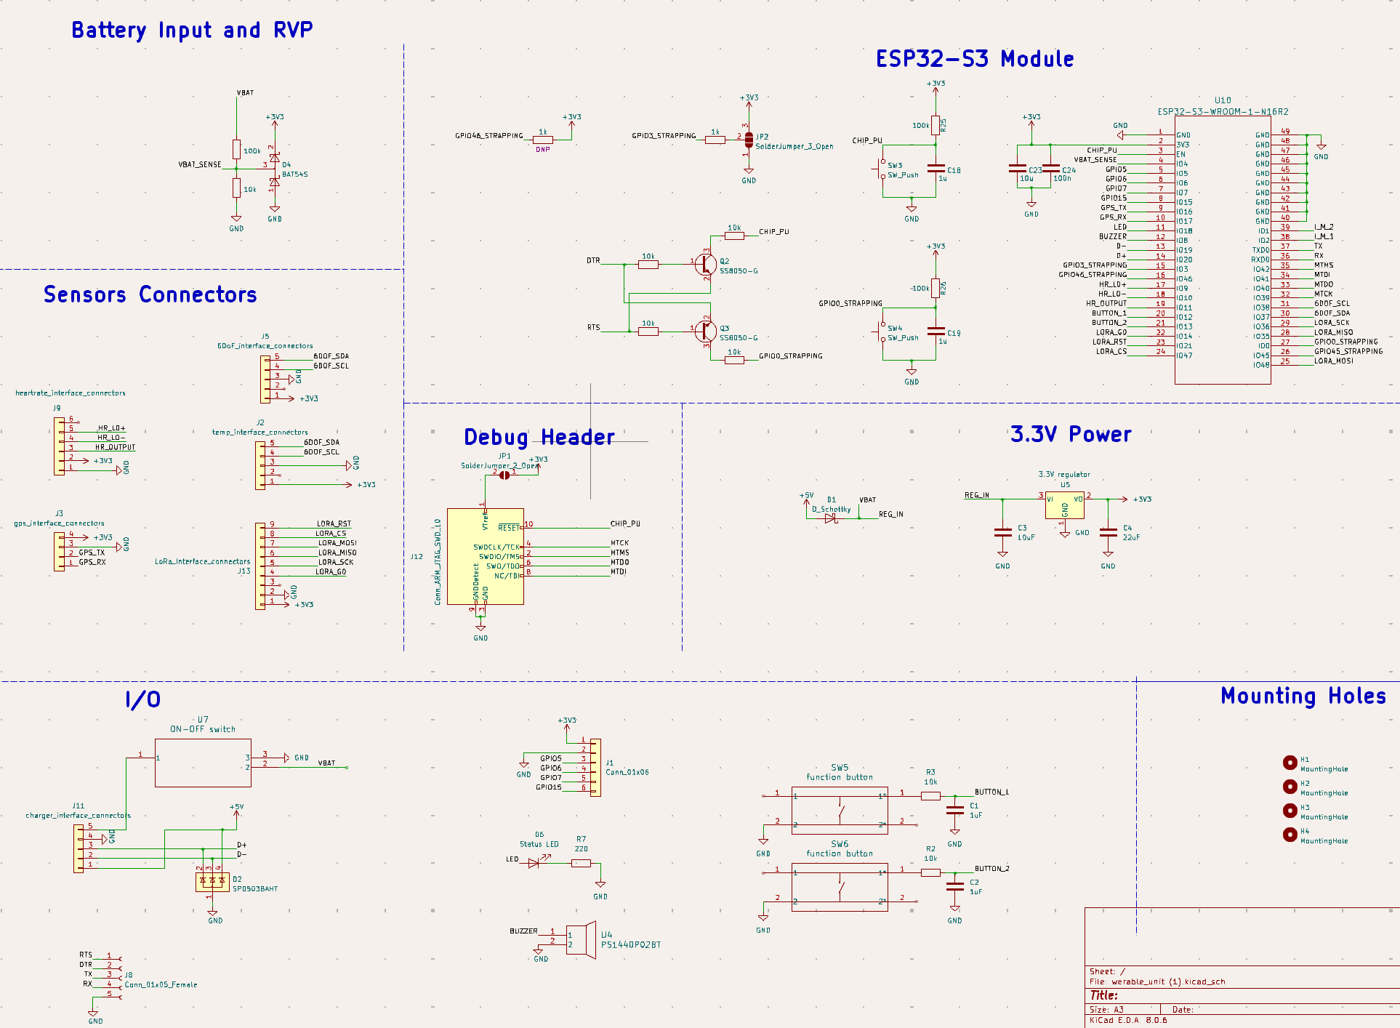
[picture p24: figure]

Figure 5. Wearable Unit Schematic Design


Figure 6. Wearable Unit PCB Layout


Figure 7. Wearable Unit Enclosure Design

### 2.2.2 Central Monitoring Hub Subsystem

The central hub acts as the control center for the network, gathering and visualizing health data

from all firefighters in real time. It allows incident commanders to monitor the team’s health

status, detect potential health risks, and respond quickly to emergencies. Its rugged design

ensures that it remains operational during operations in harsh environments. The enclosure will

be designed using 3D Computer-aided design software and printed out using a 3D printer with

Polylactic acid material (PLA). Although PLA might have lower heat-resistance, other materials

like Polyetheretherketone (PEEK) could be replaced with the same design but with higher cost.

For the purpose of this project, we will prioritize the design.

1. An ESP32-based device.
2. 3.5" TFT touch screen for data visualization and input
a. The screen should be able to visualize the firefighter data holistically
3. LoRa module for extended communication a. LoRa module must ensure a communication range of at least 1 km in open areas

and 300 meters in urban or obstructed environments

4. Buzzer to send out a critical alert to the watch commander
5. Buttons and LEDs for simple setting configuration
Requirements | Verification
The central unit display should be able to visualize the firefighter data holistically | Have three wearable device sending out simulated information to the central unit to verify it is able to display the firefighters data holistically
Send out a critical alert and change of LED color when abnormal activities occur | Manually input data with different conditions (normal, abnormal, dangerous) to the subsystem and observe whether the alert is turned on or off and whether the LED color changes according to the condition


Figure 8. Central Unit Schematic Design


Figure 9. Central Unit PCB Layout

### 2.2.3 Power Subsystem

The power subsystem ensures that both the wearable units and the central hub have the energy to

operate continuously.

1. High-capacity lithium-ion batteries (3.7V, 2000mAh for wearables and central hub)
2. Power management circuitry for efficient operation and battery protection
3. USB-C charging ports for convenient recharging
4. Battery Voltage measuring with the esp32 to ensure the user get alerts when at low

battery (below 10%)

Power Consumption for Wearable Unit:

1. ESP32 Microcontroller (DOIT ESP32 DEVKIT V1)
a. Voltage: 2.2V to 3.6V
b. Current Consumption: ~100mA to 200mA (Active)
2. Electrocardiogram Sensor (ECG/EKG Sensor) (SEN-12650)
a. Voltage: 3.3V to 5V
b. Current Consumption: ~10 mA
3. Temperature Sensor (BMP 180)
a. Voltage: 3.3V
b. Current Consumption: ~5 µA (1 sample/second in standard mode)
4. Accelerometer for Motion Detection (LSM6DS032)
a. Voltage: 1.71V to 3.6V
b. Current Consumption:~1.5 mA (Active Operation) and ~0.5 µA (Low-Power

Mode)

5. GPS Module (MAX-M10S)
a. Voltage: 3.3V VCC
b. Current Consumption: ~6mA to ~25mA
6. Buzzer (PS1240)
a. Voltage: 1.71V to 3.6V
b. Current Consumption: ~20mA
7. LoRa Module for Extended Communication (RFM95W)
a. Voltage: 1.8V to 3.7V
b. Current Consumption: 13.5 mA (Transmission) and 10 mA (Reception)

Power Consumption for Central Monitoring Unit:

1. ESP32 Microcontroller (DOIT ESP32 DEVKIT V1)
a. Voltage: 2.2V to 3.6V
b. Current Consumption: ~100mA to 200mA (Active)
2. LoRa Module for Extended Communication (RFM95W)
a. Voltage: 1.8V to 3.7V
b. Current Consumption: 13.5 mA (Transmission) and 10 mA (Reception)
3. 3.5" TFT Touch Screen (HX8357D)
a. Voltage: 3.3V
b. Current Consumption: ~20 mA to ~40 mA
4. Buzzer (PS1240)
a. Voltage: 1.71V to 3.6V
b. Current Consumption: ~20mA
Requirements | Verification
Wearable units should send alerts when the battery is low (below 10%) to the central unit. | Charge the device to 15% and operate the device until the battery drops down to 10% measuring with a multimeter to verify if the alert is sent.
Both the wearable unit and the central unit should last at least 2 hours on a single charge under typical operation conditions (temperatures above 30°C). | Simulate the sensor readings using ADALM2000, record the battery voltage every 5 mins to verify both the wearable unit and central unit has battery life longer than 2 hours.

### 2.2.4 User Interface Subsystem

The user interface is designed to provide incident commanders with a comprehensive and

intuitive platform for monitoring firefighter health data in real time. It features a custom-designed graphical user interface on a 3.5" TFT touch screen, ensuring clear visibility

and easy navigation.

Requirements | Verification
Custom-designed graphical user interface (GUI) for the 3.5" TFT touch screen | 1. Visually inspect GUI layout on the actual 3.5" screen 2. Perform touch interaction tests covering all UI elements 3. Verify responsiveness and accuracy of touch inputs
Real-time data visualization components (graphs, charts, status indicators) | 1. Simulate data input for graphs, charts, and status indicators 2. Verify real-time updates of visualizations 3. Test different data scenarios (normal, critical, edge cases) 4. Measure and verify update frequency matches requirements
Alert management system with visual and auditory cues | 1. Trigger various alert conditions 2. Verify visual cues appear correctly on screen 3. Test auditory alerts for proper sound and volume 4. Confirm alert prioritization works as designed 5. Test alert acknowledgment and dismissal functionality
User input handling for system configuration and data queries | 1. Test all system configuration options 2. Verify data query functionality with various input parameters 3. Confirm changes are applied and persist after system restart 4. Test edge cases and invalid inputs for proper error handling

### 2.2.5 Health Status Assessment Data Processing Subsystem

1. ECG/EKG Signal Processing and Analysis

a. Signal Preprocessing:
i. Use filtering techniques, such as a low-pass filter with a cut-off frequency

of 100 Hz to remove high-frequency noise, combined with a stop-band

filter around 60 Hz to eliminate electrical noise interference.

ii. | Apply the Butterworth or Chebyshev filter to ensure sufficient attenuation
| of at least -60 dB/decade in the stopband, preserving the integrity of the
| ECG signal’s primary components (P, QRS, T waves).
iii. | Evaluate the spectrum of the signal using a Fast Fourier Transform (FFT)
| to identify high-intensity peaks and confirm most energy resides in the
| low-frequency range.
iv. | Display the raw and filtered ECG signal using waveform graphs, with
| frequency components plotted based on the FFT results.
b. Heartbeat Detection:
i. Implement the Pan-Tompkins algorithm to detect the R-peaks in the ECG
| signal after filtering. This algorithm is effective in isolating the QRS
| complex while minimizing the impact of noise or other disturbances.
ii. | Use the Peak Detector subVI to locate R-peaks in real-time and extract the
| R-R intervals. Subtract the lower peak index from the higher index and
| multiply by the sampling period T = 1/fs to compute the R-R interval.
iii. | Calculate the heart rate from the R-R intervals and monitor for abnormal
| fluctuations that could indicate arrhythmias (e.g., atrial fibrillation).
2. Surrounding Temperature Monitoring
a. Calculate moving averages of surrounding temperature to smooth fluctuations.

b. Detect abnormalities in temperature trends. A sudden increase or sustained

temperature above 40°C could indicate heat exhaustion or dehydration, triggering

an alert.

3. Motion and Activity Recognition
a. Motion State Classification:
i. Use an algorithm like a finite state machine to classify motion states (e.g.,

active, running, immobile), based on acceleration of movement.

ii. | Apply thresholding techniques to accelerometer data to determine periods
| of inactivity, potentially indicating a fall or injury.
4. GPS Data Processing
a. Location Tracking and Mapping:
i. Continuously update and log the firefighter’s position.
5. Health Risk Assessment Algorithm
a. Multivariate Health Risk Scoring:
i. Combine data from heart rate, surrounding temperature, and motion
| sensors to generate a health risk score.
ii. | For instance, an elevated heart rate, combined with a rising surrounding
| temperature and lack of movement, could indicate a critical health issue
| like heat stroke or cardiac distress, triggering a high-risk alert
6. Alert System
a. Buzzer Alerts on Firefighter Suits:
i. When a critical condition is alerted, such as abnormal heart rate, high
| surrounding temperature, or low motion activity, the system will trigger a

buzzer on the firefighter’s suit. This immediate, localized alert will draw

the attention of nearby firefighters, enabling them to respond to potential

health risks or environmental dangers in real-time.

b. Central Monitoring Hub Alerts:
i. Simultaneously, the central monitoring hub will receive the same critical

alert. A loud, distinct buzzer will go off at the hub to notify supervisors of

the issue. The monitoring interface will also highlight the affected

firefighter’s status, displaying which vital sign or condition triggered the

alert and allowing for quick decision-making, such as sending backup or

ordering the firefighter to retreat for safety.

Requirements | Verification

For ECG signals, use filtering techniques, such as a low-pass filter with a cut-off frequency of 100 Hz to remove high-frequency noise, combined with a stop-band filter around 60 Hz to eliminate electrical noise interference

1. Use Matlab to plot raw and filtered ECG signals in the time domain.
2. Compare frequency spectra of raw and filtered signals using FFT.
3. Verify attenuation above 100 Hz and at 60 Hz.
4. Calculate SNR improvement.
5. Ensure no significant loss of important ECG features.
6. For ECG signals, apply the Butterworth or Chebyshev filter to ensure sufficient attenuation of at least -60 dB/decade in the stopband, preserving the integrity of the ECG signal's primary components (P, QRS,
T waves). | 1. Apply chosen filter to
known ECG signal in Matlab.
7. Measure stopband attenuation (confirm ≥ -60 dB/decade).
8. Compare original and filtered signals in time/frequency domains.
9. Quantify preservation of P, QRS, T waves (e.g., cross-correlation).

For ECG signals, apply the Butterworth or Chebyshev filter to ensure sufficient attenuation of at least -60 dB/decade in the stopband, preserving the integrity of the ECG signal’s primary components (P, QRS, T waves).

1. Apply the chosen filter (Butterworth or Chebyshev) to a known ECG signal.
2. Plot the frequency response of the filter and measure the attenuation in the stopband to confirm it meets or exceeds -60 dB/decade.
3. Compare the filtered signal with the original in both time and frequency domains to ensure preservation of P, QRS, and T waves.
4. Perform a quantitative analysis (e.g., cross-correlation) between original and filtered signals to verify integrity of primary components.

### 2.2.6 Mesh Network Integration

The LoRa Mesh Network provides long-range communication between nodes, ensuring

connectivity even when traditional communication infrastructure is unavailable. This system

enables reliable data transmission from firefighters' wearable units to the central hub in

challenging environments.

Requirements | Verification
End-to-end (including hops) data transmission time from any firefighter to the central unit shall not exceed 15 seconds, even when relaying through multiple nodes. Communication range of at least 1 km in open areas and 300 meters in urban environments. | Calculate the differences between the wearable unit packet sent time using gps time vs the central unit received time to verify the communication time is within 15 seconds.
The devices should be able to create its mesh network so even if a wearable is not directly in range to the central unit it can hop between the other wearable that’s in range to connect to the central unit | 1. Set up a test environment with multiple wearable units and obstacles to force multi-hop routing. 2. Gradually move units out of direct range of the central hub. 3. Verify data from out-of-range units successfully reaches the central hub

via other units.
4. Use network visualization tools to confirm the mesh topology.
5. Simulate node failures to test self-healing capabilities.
6. Measure and compare latency for direct vs multi-hop communications.

### 2.3 Tolerance Analysis:

### 2.3.1 LoRa Communication Range

One of the most critical aspects of the Firefighter Health Monitoring Network is the ability to

maintain reliable communication between the wearable units and the central monitoring hub. The

project relies on LoRa (Long Range) technology for extended communication, especially in

challenging environments. If the LoRa modules fail to achieve the required range, it could

compromise the entire system's effectiveness and potentially endanger firefighters' lives.

Requirement:

The LoRa module must ensure a communication range of at least 1 km in open areas and 300

meters in urban or obstructed environments.

Analysis:

To assess the feasibility of meeting this requirement, we'll consider the following factors:

- LoRa Link Budget
- Environmental Factors
- Transmission Power

### 1. LoRa Link Budget

The LoRa link budget can be calculated using the following equation:

Link Budget = Transmitter Power + Transmitter Antenna Gain - Path Loss + Receiver Antenna

Gain - Receiver Sensitivity

Assuming typical values for a LoRa system:

- Transmitter Power: 14 dBm (25 mW)
- Transmitter Antenna Gain: 2 dBi
- Receiver Antenna Gain: 2 dBi
- Receiver Sensitivity: -137 dBm (for SF12, BW125)

The path loss for 1 km in an open area can be estimated using the free-space path loss formula:

FSPL (dB) = 20 * log10(d) + 20 * log10(f) - 147.55

Where:

- d = distance in meters (1000)
- f = frequency in Hz (assume 915 MHz for US LoRa)

FSPL = 20 * log10(1000) + 20 * log10(915*10^6) - 147.55 ≈ 92 dB

Link Budget = 14 + 2 - 92 + 2 + 137 = 63 dB

This positive link budget suggests that communication at 1 km in open areas is feasible.

### 2. Environmental Factors

In urban or obstructed environments, additional path loss occurs due to obstacles. We can

estimate this additional loss to be around 20-30 dB. For 300 meters in an urban environment:

- FSPL = 20 * log10(300) + 20 * log10(915*10^6) - 147.55 ≈ 81 dB
- Total Path Loss = 81 dB + 25 dB (urban environment) = 106 dB
- Link Budget = 14 + 2 - 106 + 2 + 137 = 49 dB

This positive link budget indicates that communication at 300 meters in urban environments is

also feasible.

### 3. Transmission Power

The analysis uses 14 dBm (25 mW) as the transmission power. Many LoRa modules can transmit

at up to 20 dBm (100 mW), which would add an extra 6 dB to the link budget if needed.
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

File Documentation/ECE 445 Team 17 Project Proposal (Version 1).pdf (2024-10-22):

## ECE 445

## SENIOR DESIGN LABORATORY

# Firefighter Health Monitoring Network

# Project Proposal

### Team 17

### Bryan Chang (chchang9)

### Kevin Huang (kuanwei2)

### Steven Y M Chang (sychang5)

### TA: Surya Vasanth

### Fall 2024

# Contents

## 1. Introduction

## 2. Design

## 2.2.1. Wearable

## 2.2.2. Central Monitoring

## 2.3.2. Resilience of Mesh Network Communication….9

## 1. Introduction
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

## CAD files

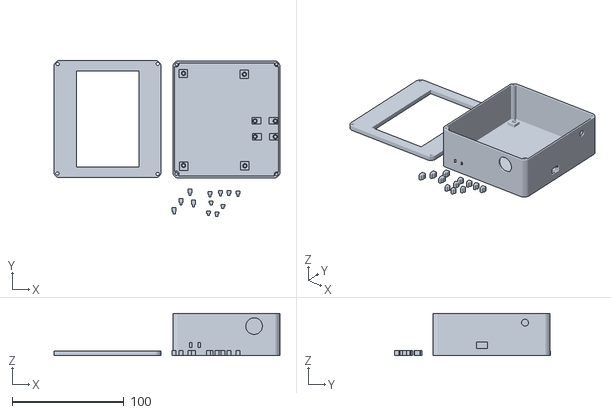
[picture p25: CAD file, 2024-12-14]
Enclosure Design/Central V2/Final Central V2.stl
202.4 x 139.7 x 38.0

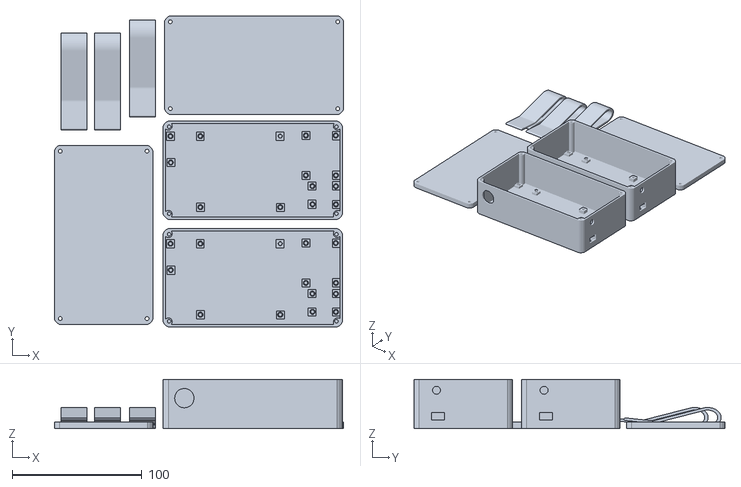
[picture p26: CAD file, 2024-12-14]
Enclosure Design/Wearable Test V1/Final Wearable Test Unit.stl
223.2 x 240.0 x 38.0

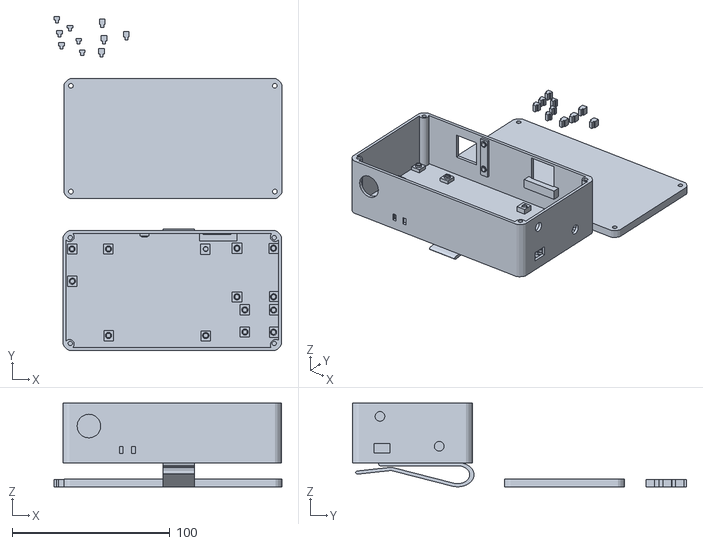
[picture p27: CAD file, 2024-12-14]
Enclosure Design/Wearable V2/Final Wearable V2.stl
144.4 x 211.6 x 53.0

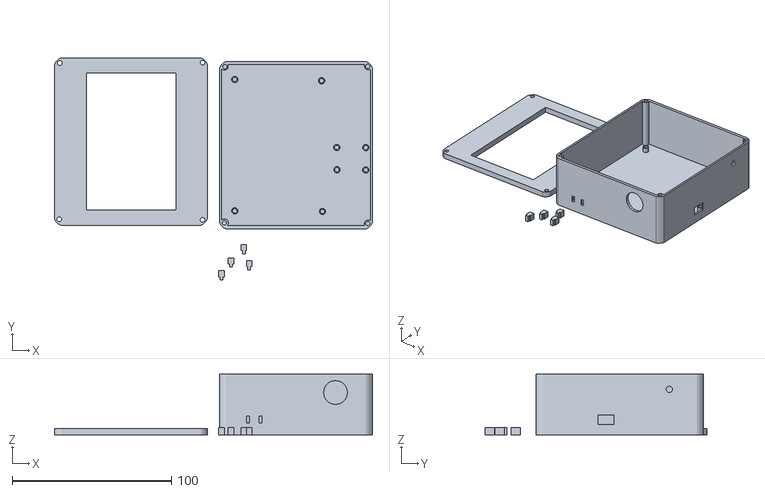
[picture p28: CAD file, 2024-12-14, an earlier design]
Enclosure Design/Central V1/Final Central.stl
199.5 x 139.4 x 38.0

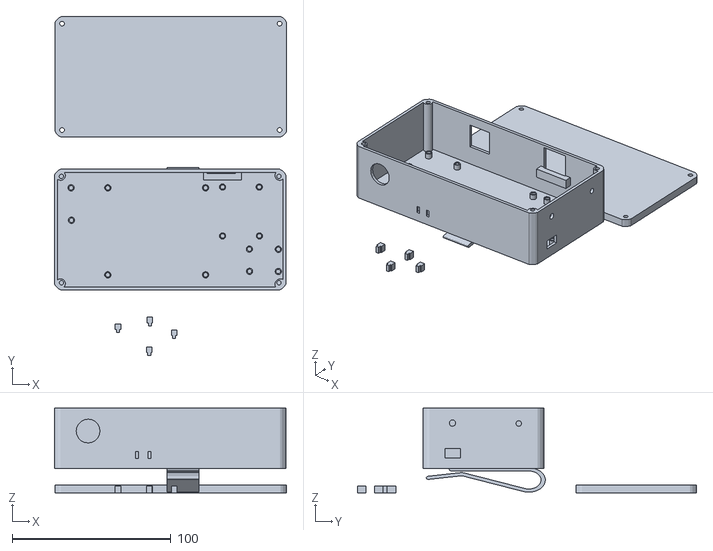
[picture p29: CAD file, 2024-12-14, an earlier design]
Enclosure Design/Wearable V1/Final Wearable.stl
146.4 x 213.5 x 53.5

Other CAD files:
Enclosure Design/Central V2/Final Central V2.gcode.3mf
Enclosure Design/Wearable Test V1/17-Final Wearable Test Unit.gcode.3mf
Enclosure Design/Wearable V2/Final Wearable V2.gcode.3mf
Enclosure Design/Central V1/Final Central.gcode.3mf
Enclosure Design/Wearable V1/Final Wearable.gcode.3mf

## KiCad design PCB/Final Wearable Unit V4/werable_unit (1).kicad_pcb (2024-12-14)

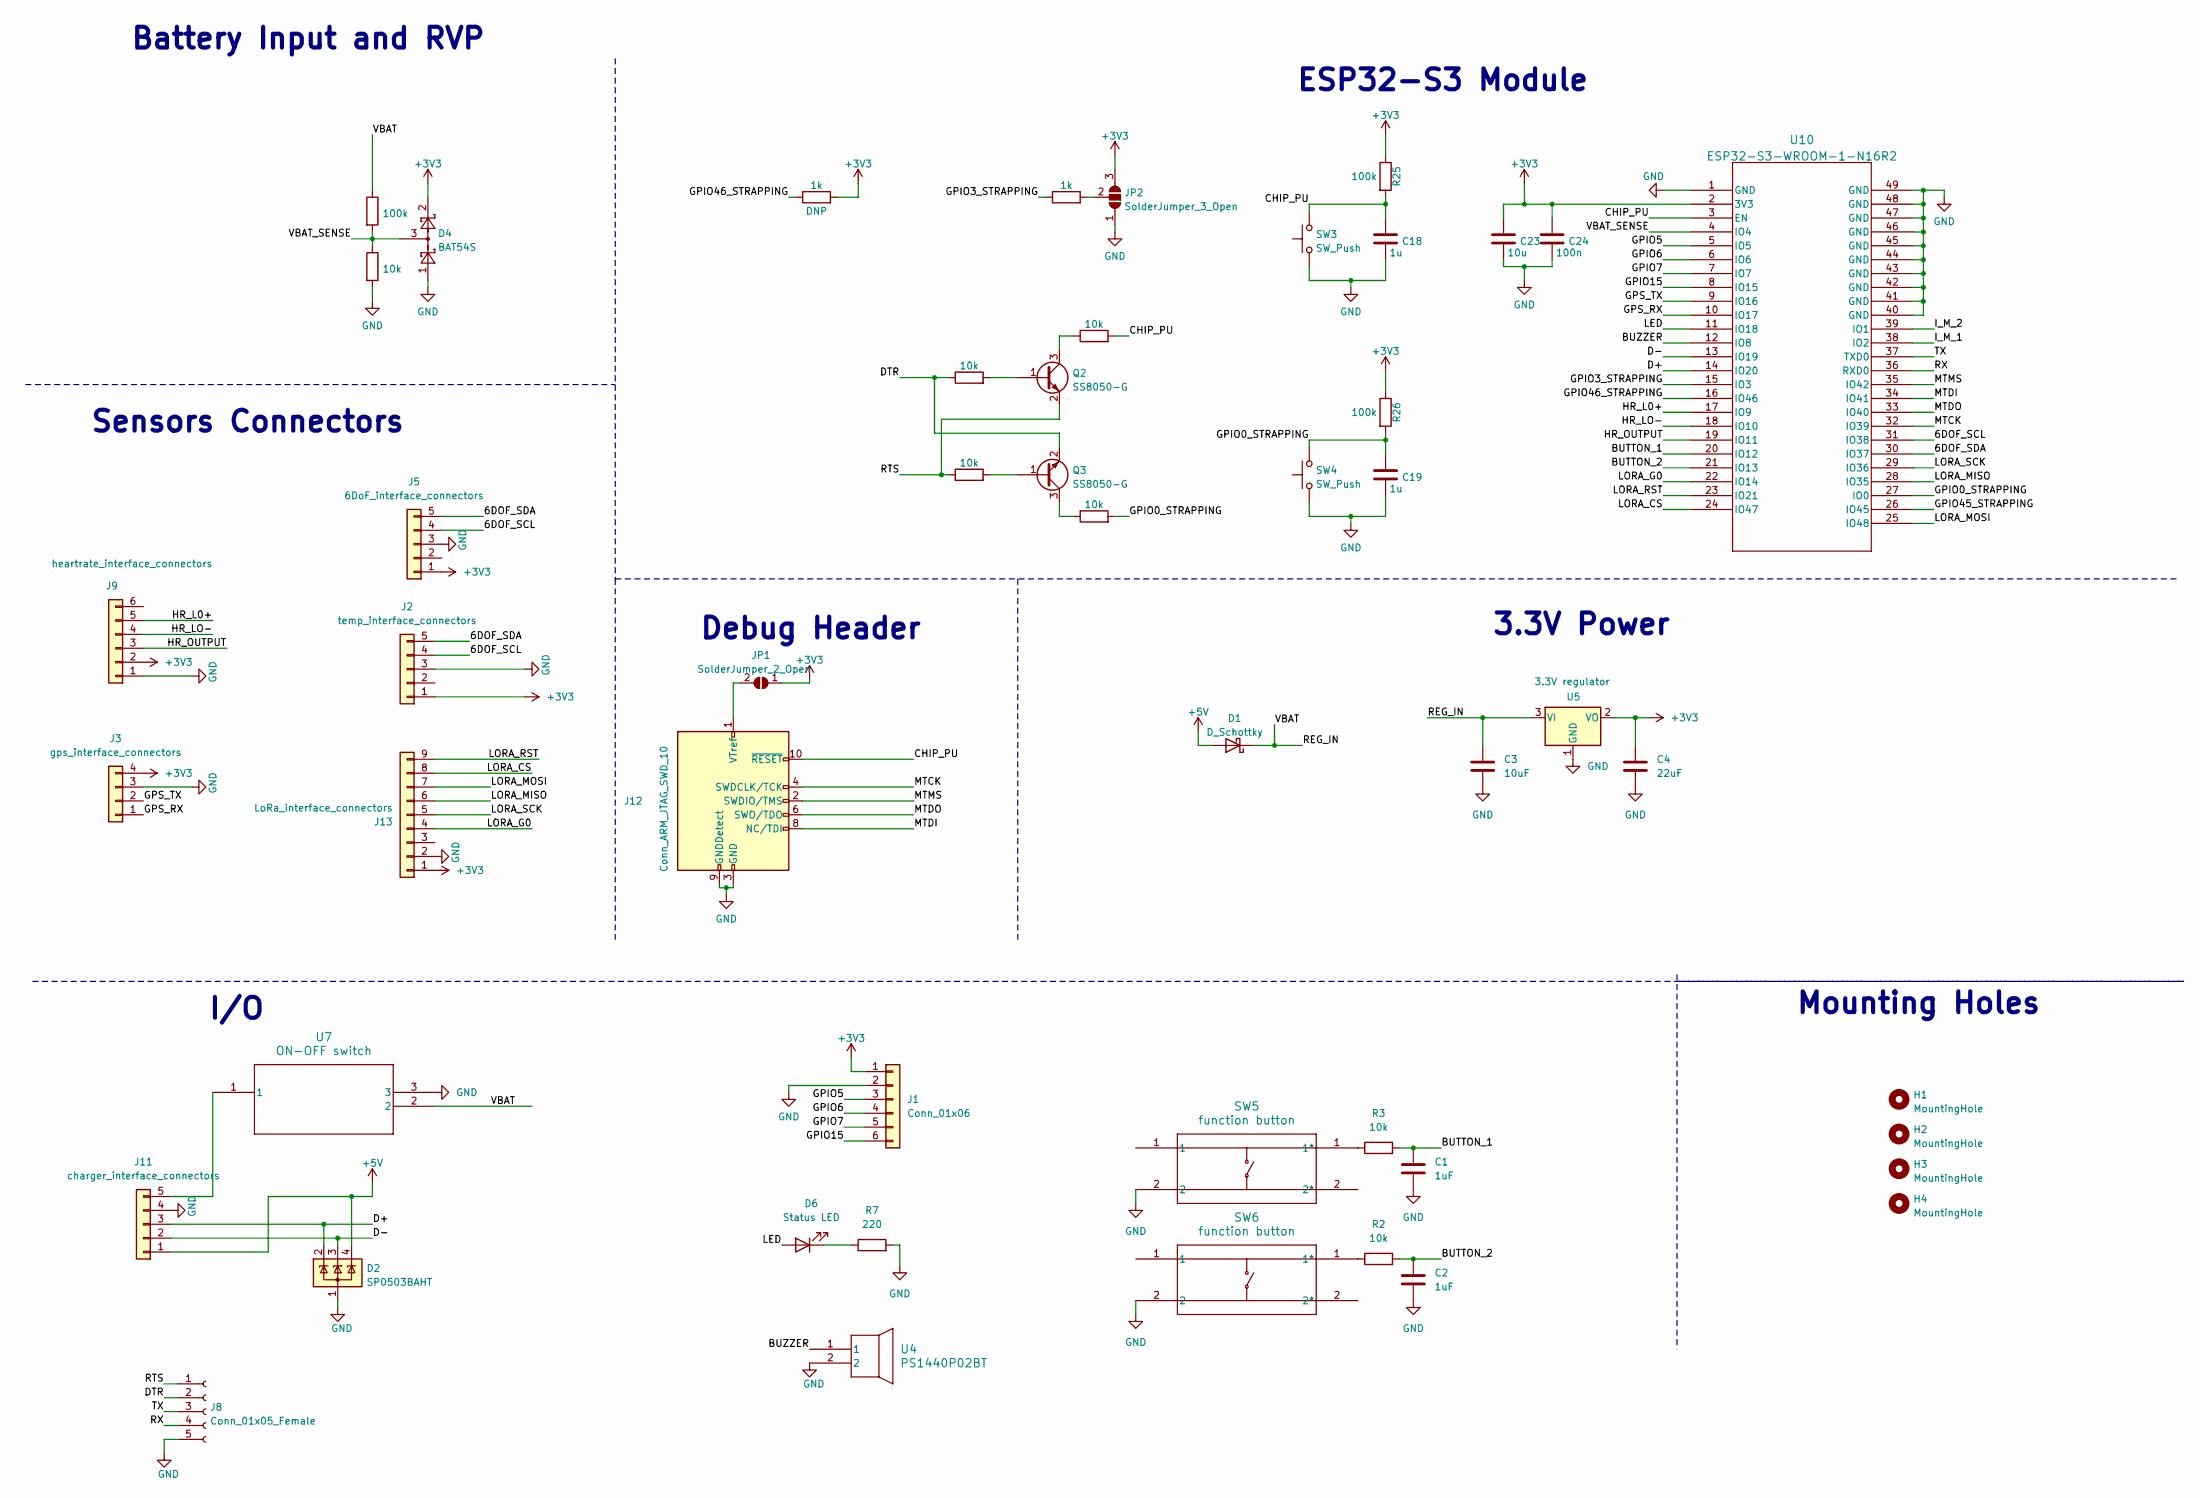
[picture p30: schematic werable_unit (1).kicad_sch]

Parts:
C1, C2: 1uF; C_0805_2012Metric_Pad1.18x1.45mm_HandSolder
C3: 10uF; C_0805_2012Metric_Pad1.18x1.45mm_HandSolder
C4: 22uF; C_0805_2012Metric_Pad1.18x1.45mm_HandSolder
C18, C19: 1u; C_0805_2012Metric_Pad1.18x1.45mm_HandSolder
C23: 10u; C_0805_2012Metric_Pad1.18x1.45mm_HandSolder
C24: 100n; C_0805_2012Metric_Pad1.18x1.45mm_HandSolder
D1: D_Schottky; D_SMA
D2: SP0503BAHT; SOT-143
D4: BAT54S; SOT-23
D6: Status LED; LED_1206_3216Metric
H1, H2, H3, H4: MountingHole; MountingHole_3.2mm_M3
J1: Conn_01x06; PinHeader_1x06_P2.54mm_Vertical
J2: temp_interface_connectors; PinHeader_1x05_P2.54mm_Vertical
J3: gps_interface_connectors; PinHeader_1x04_P2.54mm_Vertical
J5: 6DoF_interface_connectors; PinHeader_1x05_P2.54mm_Vertical
J8: Conn_01x05_Female; PinHeader_1x05_P2.54mm_Vertical
J9: heartrate_interface_connectors; PinHeader_1x06_P2.54mm_Vertical
J11: charger_interface_connectors; PinHeader_1x05_P2.54mm_Vertical
J12: Conn_ARM_JTAG_SWD_10; IDC-Header_2x05_P2.54mm_Vertical
J13: LoRa_interface_connectors; PinHeader_1x09_P2.54mm_Vertical
JP1: SolderJumper_2_Open; SolderJumper-2_P1.3mm_Open_TrianglePad1.0x1.5mm
JP2: SolderJumper_3_Open; SolderJumper-3_P2.0mm_Open_TrianglePad1.0x1.5mm
Q2, Q3: SS8050-G; SOT-23
R2, R3, R9, R14, R15, R19, R20: 10k; R_0805_2012Metric_Pad1.20x1.40mm_HandSolder
R7: 220; R_0805_2012Metric_Pad1.20x1.40mm_HandSolder
R8, R25, R26: 100k; R_0805_2012Metric_Pad1.20x1.40mm_HandSolder
R13, R18: 1k; R_0805_2012Metric_Pad1.20x1.40mm_HandSolder
SW3, SW4: SW_Push; SW_SPST_B3S-1000
SW5, SW6: function button; SW_SPST_EVQP7A
U4: PS1440P02BT; Buzzer_TDK_PS1240P02BT_D12.2mm_H6.5mm
U5: 3.3V regulator; TO-252-3_TabPin2
U7: ON-OFF switch; SW_Slide_SPDT_Angled_CK_OS102011MA1Q
U10: ESP32-S3-WROOM-1-N16R2; ESP32-S3-WROOM-1_EXP

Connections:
+3V3: C4.1, C23.1, C24.1, D4.2, J1.1, J2.1, J3.4, J5.1, J9.2 (3.3V), J13.1 (VIN), JP1.1 (A), JP2.3 (B), R13.2, R25.1, R26.1, U5.2 (VO), U10.2 (3V3)
+5V: D1.2 (A), D2.4 (K), J11.1 (5V)
/6DOF_SCL: J2.4, J5.4, U10.31 (IO38)
/6DOF_SDA: J2.5, J5.5, U10.30 (IO37)
/BUTTON_1: C1.1, R3.2, U10.20 (IO12)
/BUTTON_2: C2.1, R2.2, U10.21 (IO13)
/BUZZER: U4.1, U10.12 (IO8)
/CHIP_PU: C18.1, J12.10 (~RESET), R19.2, R25.2, SW3.2, U10.3 (EN)
/D+: D2.2 (K), J11.3 (D+), U10.14 (IO20)
/D-: D2.3 (K), J11.2 (D-), U10.13 (IO19)
/DTR: J8.2, Q3.2 (E), R14.1
/GPIO0_STRAPPING: C19.1, R20.2, R26.2, SW4.2, U10.27 (IO0)
/GPIO3_STRAPPING: R18.1, U10.15 (IO3)
/GPIO5: J1.3, U10.5 (IO5)
/GPIO6: J1.4, U10.6 (IO6)
/GPIO7: J1.5, U10.7 (IO7)
/GPIO15: J1.6, U10.8 (IO15)
/GPIO45_STRAPPING: U10.26 (IO45)
/GPIO46_STRAPPING: R13.1, U10.16 (IO46)
/GPS_RX: J3.1, U10.10 (IO17)
/GPS_TX: J3.2, U10.9 (IO16)
/HR_L0+: J9.5 (LO+), U10.17 (IO9)
/HR_LO-: J9.4 (LO-), U10.18 (IO10)
/HR_OUTPUT: J9.3 (OUTPUT), U10.19 (IO11)
/I_M_1: U10.38 (IO2)
/I_M_2: U10.39 (IO1)
/LED: D6.2 (A), U10.11 (IO18)
/LORA_CS: J13.8 (CS), U10.24 (IO47)
/LORA_G0: J13.4 (G0), U10.22 (IO14)
/LORA_MISO: J13.6 (MISO), U10.28 (IO35)
/LORA_MOSI: J13.7 (MOSI), U10.25 (IO48)
/LORA_RST: J13.9 (RST), U10.23 (IO21)
/LORA_SCK: J13.5 (SCK), U10.29 (IO36)
/MTCK: J12.4 (SWDCLK/TCK), U10.32 (IO39)
/MTDI: J12.8 (NC/TDI), U10.34 (IO41)
/MTDO: J12.6 (SWO/TDO), U10.33 (IO40)
/MTMS: J12.2 (SWDIO/TMS), U10.35 (IO42)
/RTS: J8.1, Q2.2 (E), R15.1
/RX: J8.4, U10.36 (RXD0)
/TX: J8.3, U10.37 (TXD0)
/VBAT_SENSE: D4.3, R8.2, R9.1, U10.4 (IO4)
GND: C1.2, C2.2, C3.2, C4.2, C18.2, C19.2, C23.2, C24.2, D2.1 (A), D4.1, J1.2, J2.3, J3.3, J5.3, J8.5, J9.1 (GND), J11.4 (GND), J12.3 (GND), J12.5 (GND), J12.9 (GNDDetect), J13.2 (GND), JP2.1 (A), R7.2, R9.2, SW3.1, SW4.1, SW5.2, SW6.2, U4.2, U5.1 (GND), U7.3, U10.1 (GND), U10.40 (GND), U10.41 (GND), U10.42 (GND), U10.43 (GND), U10.44 (GND), U10.45 (GND), U10.46 (GND), U10.47 (GND), U10.48 (GND), U10.49 (GND)
unnamed: D6.1 (K), R7.1
unnamed: J11.5 (BAT), U7.1
unnamed: J12.1 (VTref), JP1.2 (B)
unnamed: JP2.2 (C), R18.2
unnamed: Q2.1 (B), R14.2
unnamed: Q2.3 (C), R19.1
unnamed: Q3.1 (B), R15.2
unnamed: Q3.3 (C), R20.1
unnamed: R3.1, SW5.1 (1*)
unnamed: R2.1, SW6.1 (1*)

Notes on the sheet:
I/O
3.3V Power
Debug Header
ESP32-S3 Module
Mounting Holes
Sensors Connectors
Battery Input and RVP

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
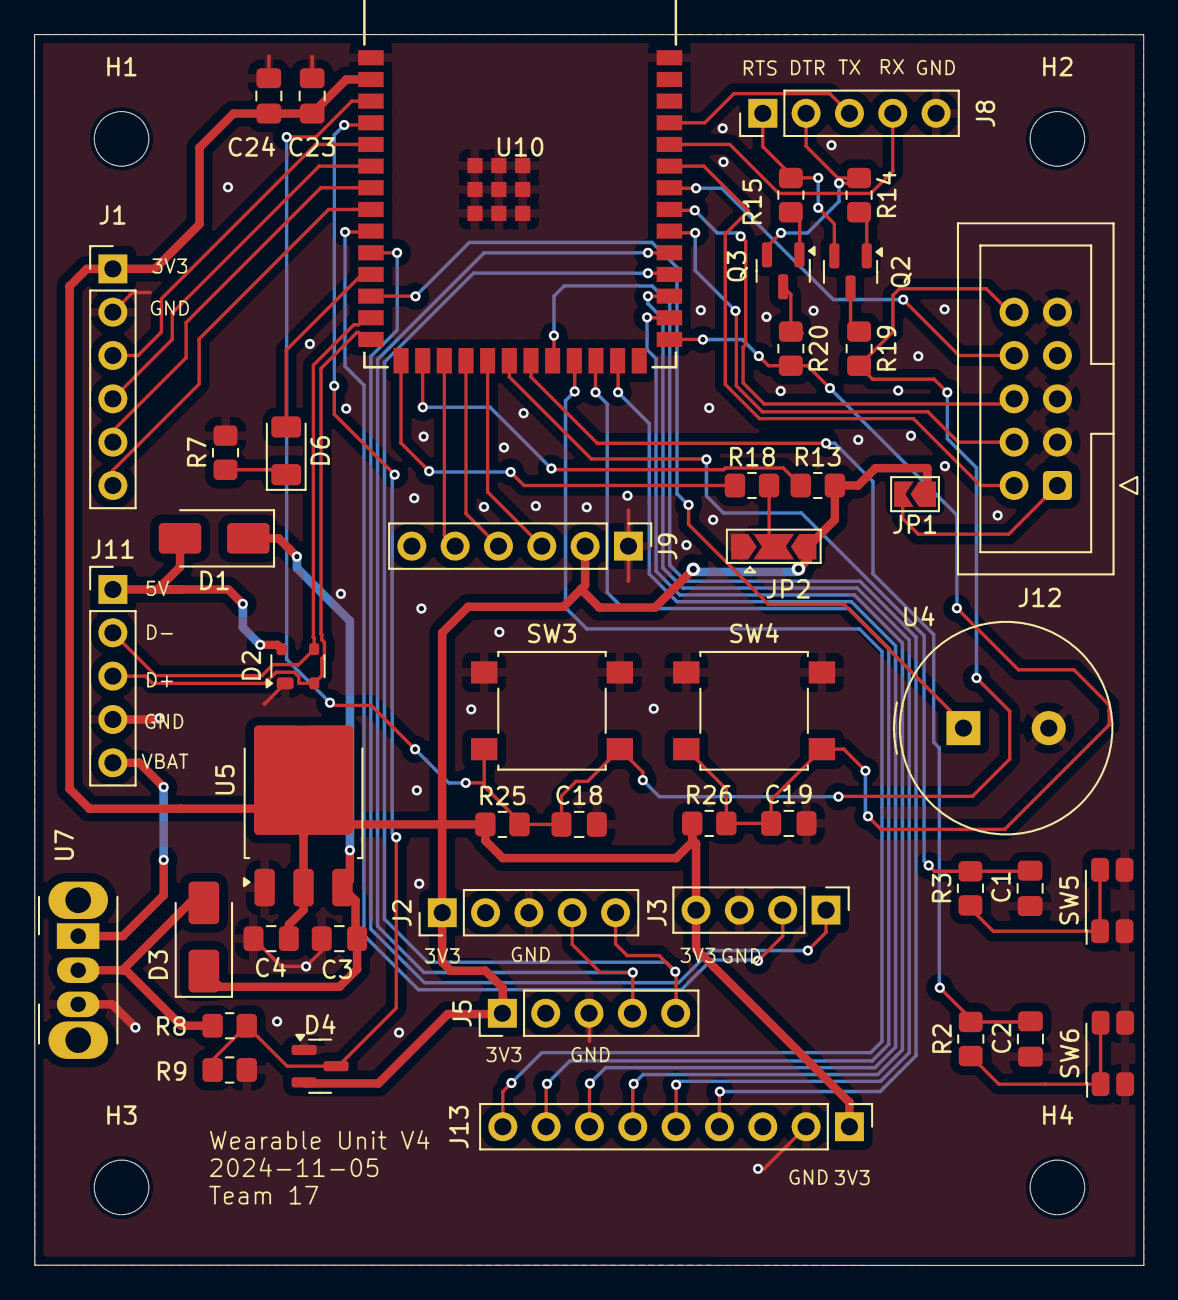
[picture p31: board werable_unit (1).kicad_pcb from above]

Board: 2 copper layers, 65.0 x 72.2 mm, 51 parts (0 on the bottom side), 51 nets.

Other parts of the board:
D3: D_Schottky; D_SMA

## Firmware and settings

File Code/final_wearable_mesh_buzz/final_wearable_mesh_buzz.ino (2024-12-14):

#include <SPI.h>
#include <LoRa.h>
#include <Wire.h>
#include <Adafruit_BMP085.h>
#include <Adafruit_LSM6DSO32.h>
#include <Adafruit_GPS.h>

Adafruit_BMP085 bmp;
Adafruit_LSM6DSO32 dso32;

// Define LoRa Pins
#define LORA_CS 47   // NSS (CS) pin
#define LORA_RST 21  // RST pin
#define LORA_IRQ 14  // DIO0 pin

// LoRa Network Settings
#define TERMINAL_NODE_ID 1 // The ID of the terminal node where messages stop
#define NODE_ID 2          // Unique ID for this node

// Maximum number of messages to track
#define MAX_TRACKED_MESSAGES 50

#define SDA_PIN 37
#define SCL_PIN 38
TwoWire customWire = TwoWire(0); // Create a custom I2C instance on port 0

#define LO_PLUS_PIN 9
#define LO_MINUS_PIN 10
#define BUZZER_PIN 8
#define LED_BUILTIN 18

// Use hardware serial port 1 for GPS (ESP32 has multiple hardware UARTs)
#define GPS_RX 16  // Connect to GPS TX
#define GPS_TX 17  // Connect to GPS RX
HardwareSerial gpsSerial(1);  // Use UART1 for GPS
Adafruit_GPS GPS(&gpsSerial);
// Set GPSECHO to 'false' to turn off echoing the GPS data to the Serial console
#define GPSECHO  true

// Buzzer timer setup
hw_timer_t* buzzerTimer = NULL;
volatile bool buzzerActive = false;
volatile int currentFreq = 0;
volatile unsigned long buzzerEndTime = 0;

int counter = 0;

// Array to store recent message IDs
unsigned long trackedMsgIDs[MAX_TRACKED_MESSAGES];
int trackedIndex = 0;

// Alert thesholds
const int HR_MAX = 150;
const int HR_MIN = -2;              // CHANGE BACK TO 40
const float TEMP_MAX = 27.0;        // CHANGE BACK TO 40
const float MOVEMENT_THRESHOLD = 0.5;
const float MS2_TO_G = 1.0 / 9.81;

// Alert timing thresholds
const unsigned long HR_ALERT_TIME = 30000;  // 30 seconds
const unsigned long TEMP_ALERT_TIME = 60000; // 3 minutes   // CHANGE BACK TO 3 minutes 180000
const unsigned long MOTION_ALERT_TIME = 60000;  // 60 seconds

// GPS update frequency
const unsigned long NORMAL_UPDATE_FREQ = 1000; // 1 second
const unsigned long EMERGENCY_UPDATE_FREQ = 500; // half a second

struct AlertStatus {
  bool isHRAlert = false;
  bool isTempAlert = false;
  bool isMotionAlert = false;
  unsigned long hrAlertStart = 0;
  unsigned long tempAlertStart = 0;
  float accX = 0.0;
  float accY = 0.0;
  float accZ = 0.0;
  unsigned long motionAlertStart = 0;
  unsigned long lastUpdate = 0;
  bool inEmergency = false;
};

// Structure to hold message details
struct LoRaMessage {
  int senderID;
  unsigned long msgID;
  String payload;
};

AlertStatus wearableAlert;

// Timer interrupt handler for buzzer
void IRAM_ATTR onBuzzerTimer() {
    static bool buzzerState = false;
    if (millis() >= buzzerEndTime) {
        digitalWrite(BUZZER_PIN, LOW);
        buzzerActive = false;
        timerAlarmDisable(buzzerTimer);
        return;
    }
    buzzerState = !buzzerState;
    digitalWrite(BUZZER_PIN, buzzerState);
}

// Non-blocking version of playTone
void playToneNB(int frequency, int duration) {
    if (buzzerActive) return;
    
    buzzerActive = true;
    currentFreq = frequency;
    buzzerEndTime = millis() + duration;
    
    unsigned long period = 1000000 / frequency;
    timerAlarmWrite(buzzerTimer, period / 2, true);
    timerAlarmEnable(buzzerTimer);
}

// Non-blocking version of playSiren
void playSirenNB() {
    static int sirenStep = 0;
    static int currentFreq = 2000;
    static bool ascending = true;
    
    if (!buzzerActive) {
        if (ascending) {
            currentFreq += 200;
            if (currentFreq >= 4000) ascending = false;
        } else {
            currentFreq -= 200;
            if (currentFreq <= 2000) {
                ascending = true;
                sirenStep++;
            }
        }
        
        if (sirenStep < 3) {
            playToneNB(currentFreq, 20);
        } else {
            sirenStep = 0;
        }
    }
}

// Non-blocking version of playUrgentBeeps
void playUrgentBeepsNB() {
    static int beepCount = 0;
    static unsigned long lastBeepTime = 0;
    const int BEEP_INTERVAL = 60; // 30ms on + 30ms off
    
    if (!buzzerActive && (millis() - lastBeepTime >= BEEP_INTERVAL)) {
        if (beepCount < 8) {
            playToneNB(4000, 30);
            beepCount++;
            lastBeepTime = millis();
        } else {
            beepCount = 0;
        }
    }
}

// Non-blocking version of playWarningPattern
void playWarningPatternNB() {
    static unsigned long lastPatternTime = 0;
    const unsigned long PATTERN_INTERVAL = 1000;
    
    if (millis() - lastPatternTime >= PATTERN_INTERVAL) {
        playUrgentBeepsNB();
        lastPatternTime = millis();
    }
}

void setup() {
    // Initialize Serial Monitor
    Serial.begin(115200);
    while (!Serial);

    // Initialize LoRa
    SPI.begin(36, 35, 48, 47);
    LoRa.setPins(LORA_CS, LORA_RST, LORA_IRQ);
    if (!LoRa.begin(915E6)) {
        Serial.println("LoRa initialization failed!");
        while (1);
    }
    
    Serial.print("Node ");
    Serial.print(NODE_ID);
    Serial.println(" initialized");

    Serial.println("Sensors Test!");
    customWire.begin(SDA_PIN, SCL_PIN);

    // Temperature Setup
    if (!bmp.begin(0x6A, &customWire)) {
        while (1) delay(10);
    }
    Serial.println("BMP180 Found!");

    // Heartrate Setup
    pinMode(LO_PLUS_PIN, INPUT);
    pinMode(LO_MINUS_PIN, INPUT);
    Serial.println("Heartrate Sensor Found!");

    // LSM6DSO32 Setup
    if (!dso32.begin_I2C(0x6A, &customWire)) {
        while (1) delay(10);
    }
    Serial.println("LSM6DSO32 Found!");
    dso32.setAccelRange(LSM6DSO32_ACCEL_RANGE_8_G);

    // GPS setup
    gpsSerial.begin(9600, SERIAL_8N1, GPS_RX, GPS_TX);
    GPS.begin(9600);
    GPS.sendCommand(PMTK_SET_NMEA_OUTPUT_RMCGGA);
    GPS.sendCommand(PMTK_SET_NMEA_UPDATE_1HZ);
    GPS.sendCommand(PGCMD_ANTENNA);

    delay(1000);
    gpsSerial.println(PMTK_Q_RELEASE);

    // Buzzer Setup
    pinMode(BUZZER_PIN, OUTPUT);
    buzzerTimer = timerBegin(1, 80, true);
    timerAttachInterrupt(buzzerTimer, &onBuzzerTimer, true);

    // LED Setup
    pinMode(LED_BUILTIN, OUTPUT);
}

void loop() {
    // Check for incoming LoRa packets
    int packetSize = LoRa.parsePacket();
    if (packetSize) {
        handleLoRaPacket();
    }

    // Read sensors
    float temperature = bmp.readTemperature();
    sensors_event_t accel, gyro, temp;
    dso32.getEvent(&accel, &gyro, &temp);

    float ax = accel.acceleration.x;
    float ay = accel.acceleration.y;
    float az = accel.acceleration.z;
    float dynamic_acceleration = abs(sqrt(pow(ax*MS2_TO_G, 2) + 
                                       pow(ay*MS2_TO_G, 2) + 
                                       pow(az*MS2_TO_G, 2)) - 1.0);

    // Heartrate Reading
    int heartRateValue = readHeartRate();

    // GPS Reading
    handleGPS();

    // Print sensor data
    printSensorData(temperature, ax, ay, az, dynamic_acceleration, heartRateValue);

    // Check alerts
    checkAlerts(temperature, ax, ay, az, heartRateValue);

    // Handle emergency state
    if (wearableAlert.inEmergency) {
        playWarningPatternNB();
    }

    // Send periodic updates
    handlePeriodicUpdates(temperature, dynamic_acceleration, heartRateValue);

    delay(100);
}

void handleLoRaPacket() {
    int senderID = LoRa.read();
    int numHop = LoRa.read();
    
    unsigned long msgID = 0;
    msgID |= (unsigned long)LoRa.read() << 24;
    msgID |= (unsigned long)LoRa.read() << 16;
    msgID |= (unsigned long)LoRa.read() << 8;
    msgID |= (unsigned long)LoRa.read();

    float passTemp = (float)LoRa.read();
    float passAcc = (float)LoRa.read();
    int passHR = (int)LoRa.read();
    int TempAlert = (int)LoRa.read();
    int MotionAlert = (int)LoRa.read();
    int HRAlert = (int)LoRa.read();
    String passGPS = LoRa.readString();

    if (isDuplicate(msgID)) {
        Serial.println("Duplicate message. Ignoring.");
        return;
    }

    trackMessage(msgID);
    sendForwardMessage(senderID, numHop, msgID, passTemp, passAcc, passHR, 
                      passGPS, TempAlert, MotionAlert, HRAlert);
}

int readHeartRate() {
    if ((digitalRead(9) == 1) || (digitalRead(10) == 1)) {
        Serial.println("No Heart Rate Reading");
        return -1;
    }
    return analogRead(11);
}

void handleGPS() {
    char c = GPS.read();
    if ((c) && (GPSECHO)) Serial.write(c);
    if (GPS.newNMEAreceived()) {
        GPS.parse(GPS.lastNMEA());
    }
}

void printSensorData(float temperature, float ax, float ay, float az, 
                    float dynamic_acceleration, int heartRateValue) {
    Serial.println("Temperature = " + String(temperature));
    Serial.println("Acceleration: x = " + String(ax) + " y = " + String(ay) + 
                  " z = " + String(az));
    Serial.println("Dynamic Acceleration = " + String(dynamic_acceleration) + "G");
    Serial.println("Heartrate Measurement = " + String(heartRateValue));
    Serial.println();
}

void handlePeriodicUpdates(float temperature, float acceleration, int heartRateValue) {
    unsigned long updateInterval = wearableAlert.inEmergency ? 
                                 EMERGENCY_UPDATE_FREQ : NORMAL_UPDATE_FREQ;

    unsigned long currentTime = millis();
    if (currentTime - wearableAlert.lastUpdate >= updateInterval) {
        String gps = GPS.fix ? formatGPSData() : "no GPS signal";
        sendMessage(temperature, acceleration, heartRateValue, gps, 
                   wearableAlert.isTempAlert, wearableAlert.isMotionAlert, 
                   wearableAlert.isHRAlert);
        wearableAlert.lastUpdate = currentTime;
    }
}

// [Previous helper functions remain the same: noMovement, checkAlerts, 
// trackMessage, isDuplicate, sendMessage, sendForwardMessage, formatGPSData]
// Adding them here for completeness but truncated for space

bool noMovement(float ax, float ay, float az) {
    bool no_movement = (abs(ax - wearableAlert.accX) < MOVEMENT_THRESHOLD ||
                       abs(ay - wearableAlert.accY) < MOVEMENT_THRESHOLD ||
                       abs(az - wearableAlert.accZ) < MOVEMENT_THRESHOLD);
    
    wearableAlert.accX = ax;
    wearableAlert.accY = ay;
    wearableAlert.accZ = az;

    return no_movement;
}

void checkAlerts(float temperature, float ax, float ay, float az, int heartRateValue) {
    unsigned long currentTime = millis();
    
    // Heart Rate Alert Check
    if (heartRateValue > HR_MAX || heartRateValue < HR_MIN) {
        if (wearableAlert.hrAlertStart == 0) {
            wearableAlert.hrAlertStart = currentTime;
        } else if (currentTime - wearableAlert.hrAlertStart > HR_ALERT_TIME) {
            wearableAlert.isHRAlert = true;
        }
    } else {
        wearableAlert.isHRAlert = false;
        wearableAlert.hrAlertStart = 0;
    }

    // Temperature Alert Check
    if (temperature > TEMP_MAX) {
        if (wearableAlert.tempAlertStart == 0) {
            wearableAlert.tempAlertStart = currentTime;
        } else if (currentTime - wearableAlert.tempAlertStart > TEMP_ALERT_TIME) {
            wearableAlert.isTempAlert = true;
        }
    } else {
        wearableAlert.isTempAlert = false;
        wearableAlert.tempAlertStart = 0;
    }

    // Motion Alert Check
    if (noMovement(ax, ay, az)) {
        if (wearableAlert.motionAlertStart == 0) {
            wearableAlert.motionAlertStart = currentTime;
        } else if (currentTime - wearableAlert.motionAlertStart > MOTION_ALERT_TIME) {
            wearableAlert.isMotionAlert = true;
        }
    } else {
        wearableAlert.isMotionAlert = false;
        wearableAlert.motionAlertStart;
    }

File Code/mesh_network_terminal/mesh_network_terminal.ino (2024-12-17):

#include <SPI.h>
#include <LoRa.h>
#include <Adafruit_GFX.h>
#include <Adafruit_HX8357.h>

// Buzzer Pin
#define BUZZER_PIN 8

// TFT Pins
#define TFT_CS 5     // TFT CS pin
#define TFT_RST 10   // TFT RST pin
#define TFT_DC 15    // TFT DC pin

// Define LoRa Pins
#define LORA_CS 47   // NSS (CS) pin
#define LORA_RST 21  // RST pin
#define LORA_IRQ 14  // DIO0 pin

// LoRa Network Settings
#define TERMINAL_NODE_ID 1 // The ID of the terminal node where messages stop
#define NODE_ID 1          // Unique ID for this node

// Maximum number of messages to track
#define MAX_TRACKED_MESSAGES 50

// Battery Variables
const int VBAT_SENSE_PIN = 4;  // GPIO pin 4 (ADC1_CH3) for battery sensing
const float DIVIDER_RATIO = 12.0;  // Voltage divider ratio (100k + 10k) / 10k = 11
const float ADC_REFERENCE = 3.3;  // ESP32 ADC reference voltage
const float ADC_RESOLUTION = 4095.0;  // ESP32 has 12-bit ADC (2^12 - 1)
                        

float battery1;
float battery2;
long batteryCentral;
int timeInterval;
int batteryAlert1;
int batteryAlert2;
int batteryCentralAlert;
int battery1Time;
int battery2Time;
int last_update;
int update;

// TFT Variables
int infoWidth;
int infoHeight;
int boxWidth;
int boxHeight;
int infoBox_x;
int infoBox_y;
int node2Box_x;
int node2Box_y;
int node3Box_x;
int node3Box_y;
int row_height;

// Row of Text
int gps_row;
int temp_row;
int heart_row;
int accel_row;
int hop_row;
int signal_row;
int image_row;
int battery_row;

// Text Cursor
int gpsCursor1;
int tempCursor1;
int heartCursor1;
int accelCursor1;
int hopCursor1;
int signalCursor1;
int batteryCursor1;

int gpsCursor2;
int tempCursor2;
int heartCursor2;
int accelCursor2;
int hopCursor2;
int signalCursor2;
int batteryCursor2;

int lastReceivedNode2;
int lastReceivedNode3;

bool heartState=true;

// TFT Setup (assuming 320x480 HX8357 screen)
Adafruit_HX8357 tft = Adafruit_HX8357(TFT_CS, TFT_DC, TFT_RST);

// Array to store recent message IDs
unsigned long trackedMsgIDs[MAX_TRACKED_MESSAGES];
int trackedIndex = 0;

const uint8_t battery100[] = {
    0b11111111, 0b11111111, 0b11111111, 0b11111100, // Row 1
    0b11111111, 0b11111111, 0b11111111, 0b11111100, // Row 2 (top of the battery body)
    0b11100000, 0b00000000, 0b00000000, 0b00001111, // Row 3
    0b11101111, 0b10111110, 0b11111011, 0b11101111, // Row 4 (battery charge)
    0b11101111, 0b10111110, 0b11111011, 0b11101111, // Row 5
    0b11101111, 0b10111110, 0b11111011, 0b11101111, // Row 6
    0b11101111, 0b10111110, 0b11111011, 0b11101111, // Row 7
    0b11101111, 0b10111110, 0b11111011, 0b11101111, // Row 8
    0b11101111, 0b10111110, 0b11111011, 0b11101111, // Row 9
    0b11101111, 0b10111110, 0b11111011, 0b11101111, // Row 10 (battery charge)
    0b11101111, 0b10111110, 0b11111011, 0b11101111, // Row 11
    0b11101111, 0b10111110, 0b11111011, 0b11101111, // Row 12
    0b11101111, 0b10111110, 0b11111011, 0b11101111, // Row 13
    0b11100000, 0b00000000, 0b00000000, 0b00001111, // Row 14 (bottom of the battery body)
    0b11111111, 0b11111111, 0b11111111, 0b11111100, // Row 15
    0b11111111, 0b11111111, 0b11111111, 0b11111100  // Row 16
};

const uint8_t battery75[] = {
    0b11111111, 0b11111111, 0b11111111, 0b11111100, // Row 1
    0b11111111, 0b11111111, 0b11111111, 0b11111100, // Row 2 (top of the battery body)
    0b11100000, 0b00000000, 0b00000000, 0b00001111, // Row 3
    0b11101111, 0b10111110, 0b11111000, 0b00001111, // Row 4 (battery charge)
    0b11101111, 0b10111110, 0b11111000, 0b00001111, // Row 5
    0b11101111, 0b10111110, 0b11111000, 0b00001111, // Row 6
    0b11101111, 0b10111110, 0b11111000, 0b00001111, // Row 7
    0b11101111, 0b10111110, 0b11111000, 0b00001111, // Row 8
    0b11101111, 0b10111110, 0b11111000, 0b00001111, // Row 9
    0b11101111, 0b10111110, 0b11111000, 0b00001111, // Row 10 (battery charge)
    0b11101111, 0b10111110, 0b11111000, 0b00001111, // Row 11
    0b11101111, 0b10111110, 0b11111000, 0b00001111, // Row 12
    0b11101111, 0b10111110, 0b11111000, 0b00001111, // Row 13
    0b11100000, 0b00000000, 0b00000000, 0b00001111, // Row 14 (bottom of the battery body)
    0b11111111, 0b11111111, 0b11111111, 0b11111100, // Row 15
    0b11111111, 0b11111111, 0b11111111, 0b11111100  // Row 16
};

const uint8_t battery50[] = {
    0b11111111, 0b11111111, 0b11111111, 0b11111100, // Row 1
    0b11111111, 0b11111111, 0b11111111, 0b11111100, // Row 2 (top of the battery body)
    0b11100000, 0b00000000, 0b00000000, 0b00001111, // Row 3
    0b11101111, 0b10111110, 0b00000000, 0b00001111, // Row 4 (battery charge)
    0b11101111, 0b10111110, 0b00000000, 0b00001111, // Row 5
    0b11101111, 0b10111110, 0b00000000, 0b00001111, // Row 6
    0b11101111, 0b10111110, 0b00000000, 0b00001111, // Row 7
    0b11101111, 0b10111110, 0b00000000, 0b00001111, // Row 8
    0b11101111, 0b10111110, 0b00000000, 0b00001111, // Row 9
    0b11101111, 0b10111110, 0b00000000, 0b00001111, // Row 10 (battery charge)
    0b11101111, 0b10111110, 0b00000000, 0b00001111, // Row 11
    0b11101111, 0b10111110, 0b00000000, 0b00001111, // Row 12
    0b11101111, 0b10111110, 0b00000000, 0b00001111, // Row 13
    0b11100000, 0b00000000, 0b00000000, 0b00001111, // Row 14 (bottom of the battery body)
    0b11111111, 0b11111111, 0b11111111, 0b11111100, // Row 15
    0b11111111, 0b11111111, 0b11111111, 0b11111100  // Row 16
};

const uint8_t battery25[] = {
    0b11111111, 0b11111111, 0b11111111, 0b11111100, // Row 1
    0b11111111, 0b11111111, 0b11111111, 0b11111100, // Row 2 (top of the battery body)
    0b11100000, 0b00000000, 0b00000000, 0b00001111, // Row 3
    0b11101111, 0b10000000, 0b00000000, 0b00001111, // Row 4 (battery charge)
    0b11101111, 0b10000000, 0b00000000, 0b00001111, // Row 5
    0b11101111, 0b10000000, 0b00000000, 0b00001111, // Row 6
    0b11101111, 0b10000000, 0b00000000, 0b00001111, // Row 7
    0b11101111, 0b10000000, 0b00000000, 0b00001111, // Row 8
    0b11101111, 0b10000000, 0b00000000, 0b00001111, // Row 9
    0b11101111, 0b10000000, 0b00000000, 0b00001111, // Row 10 (battery charge)
    0b11101111, 0b10000000, 0b00000000, 0b00001111, // Row 11
    0b11101111, 0b10000000, 0b00000000, 0b00001111, // Row 12
    0b11101111, 0b10000000, 0b00000000, 0b00001111, // Row 13
    0b11100000, 0b00000000, 0b00000000, 0b00001111, // Row 14 (bottom of the battery body)
    0b11111111, 0b11111111, 0b11111111, 0b11111100, // Row 15
    0b11111111, 0b11111111, 0b11111111, 0b11111100  // Row 16
};
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

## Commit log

2024-11-06 order forms update
    [ECE 445 Order Form 2.xls, ECE 445 Order Form.xls]
2024-11-06 adding heartrate, temperature, and accelerometer sketches
2024-11-20 adding sensor code
2024-11-21 wearable unit buzzer update
    [final_wearable_mesh.ino, final_wearable_mesh_buzz.ino]
2024-12-14 design documents
    [17-Final Wearable Test Unit.gcode.3mf, ECE 445 Order Form 2.xls, ECE 445 Order Form.xls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]
